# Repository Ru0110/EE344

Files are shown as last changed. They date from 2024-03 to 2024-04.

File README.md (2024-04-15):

# EE344
Auto-dialling Alarm System for Temperature and Humidity Monitoring

## File organization
The following folders will be present in the root directory of the project:
- `energy_meter`: Contains KiCad design files for the sensing unit PCB
- `Software`: Contains all firmware used in the project
    - `RP2040_code`: Source code for the firmware of the sensing unit written using the RP2040 C/C++ SDK. The code may be built using CMake or the uf2 file in the build subdirectory may be flashed directly to the RPi Pico W.
    - `arduino_code`: Source code for the sensing unit based on arduino. Based on code provided by Analog Devices for the EVAL-ACE9000 SHIELDZ board.
    - `central_code`: Source code for the central unit written in MicroPython
    - Other python files are for setting up a TCP client to test data logging
- `CAD`: Contains files for the enclosures of the sensing unit and central unit  
- `Test`: Contains test data from a long-term test using an Air Conditioner
- `central_unit`: Contains KiCad design files for a central unit with a SIM800L module. This is not used in the final prototype but may be useful for future iterations
- `Website`: Contains Code for a locally hosted website to view real-time data from the sensing units 
- Documentation file
- README file (this file)

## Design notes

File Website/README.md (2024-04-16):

## Project Overview

This project includes the following HTML and CSS files:

* `index.html`: The main HTML page for the project.
* `style.css`: Stylesheet for the HTML page.

## Deployment

The HTML page is deployed using GitHub Pages and is currently accessible at: https://shleshgholap.github.io/EDL-Project/

## Waveform Visualization

* The `Waveform.html` file displays plots of voltage values and their periodograms. Currently, this visualization relies on a local server.
* **Enhancement:** To make the waveform visualization publicly accessible, consider migrating the plot generation process to a cloud computing service. This would enable seamless integration of the plots into the `index.html` page. 

**Key Points**

* The core HTML and CSS components are ready for deployment.
* The waveform visualization component requires modification to work within a publicly accessible deployment setup.

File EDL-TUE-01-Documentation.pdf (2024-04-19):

Auto-dialing Alarm System for Power,

# Temperature, and Humidity Monitoring

## EE344: Electronic Design Lab Group TUE-01

## Abhiruchi Kotamkar (2100700043) Shiv Bharuka (210070079) Shlesh Gholap (210070080) Shobhit Maheshwari (210070081)

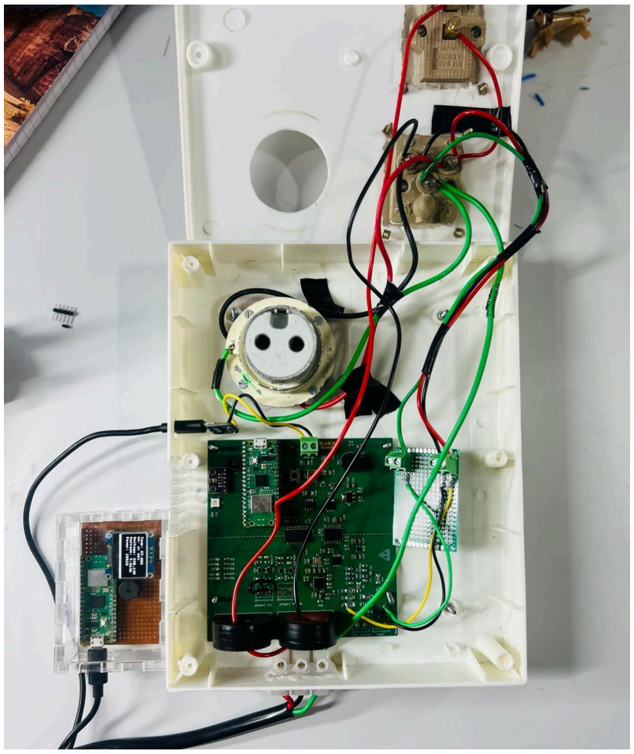
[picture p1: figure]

# Table of contents

Features and Overview | 3
File organization | 3
Hardware documentation | 4
Sensing unit | 4
Changes from the EVAL-ADE9000 SHIELDZ | 4
Isolation circuitry | 5
Voltage and current channel calculations | 5
Other peripherals | 5
Troubleshooting | 5
Central unit | 6
Modules | 6
Software documentation | 7
Sensing unit | 7
ADE9000 driver | 7
BME280 driver | 7
Wireless communication | 7
EEPROM in Flash | 7
Central unit | 7
OLED Display | 8
Buzzer | 8
MongoDB | 8
Website | 9
Push Notifications and Mailing | 9
Possible future work | 10
Additional references | 10

# Features and Overview

- Continuous health monitoring and alarm system for high-power appliances such as Air Conditioners, Humidity Regulators, Lab equipment, and all appliances up to 20kW.
- Machine health monitoring by analyzing harmonic distortions in voltage waveform
- Data such as power consumption, local temperature and humidity, and voltage waveform are uploaded to a remote database accessible from anywhere.
- Multi-unit integration over LAN in a setting such as a laboratory or factory with the help of a central unit that coordinates data logging.
- Alarm system with push notifications, email, and call-based alarms on user-defined thresholds for all monitored values provided by the central unit

# File organization

The following folders will be present in the root directory of the project:
- energy_meter: Contains KiCad design files for the sensing unit PCB
- Software: Contains all firmware used in the project
- RP2040_code: Source code for the firmware of the sensing unit written using the RP2040 C/C++ SDK. The code may be built using CMake or the uf2 file in the build subdirectory may be flashed directly to the RPi Pico W.
- arduino_code: Source code for the sensing unit based on arduino. Based on code provided by Analog Devices for the EVAL-ACE9000 SHIELDZ board.
- central_code: Source code for the central unit written in MicroPython
- Other python files are for setting up a TCP client to test data logging
- CAD: Contains files for the enclosures of the sensing unit and central unit
- Test: Contains test data from a long-term test using an Air Conditioner
- central_unit: Contains KiCad design files for a central unit with a SIM800L module. This is not used in the final prototype but may be useful for future iterations
- Website: Contains Code for a locally hosted website to view real-time data from the sensing units
- README file
- Documentation file (this file)

This documentation may be changed. Find the live version here: https://docs.google.com/document/d/e/2PACX-1vSk20U0GbC1EArys-i2jhloWY60GNWYztmFV4l-aTbJ1UrM4m5yABL2bQwfzQ4_mtzRKHXNJLR0H1ZW/pub (https://docs.google.com/document/d/e/2PACX-1vSk20U0GbC1EArys-i2jhloWY60GNWYztmFV4l-aTbJ1UrM4m5yABL2bQwfzQ4_mtzRKHXNJLR0H1ZW/pub)

# Hardware documentation

## Sensing unit

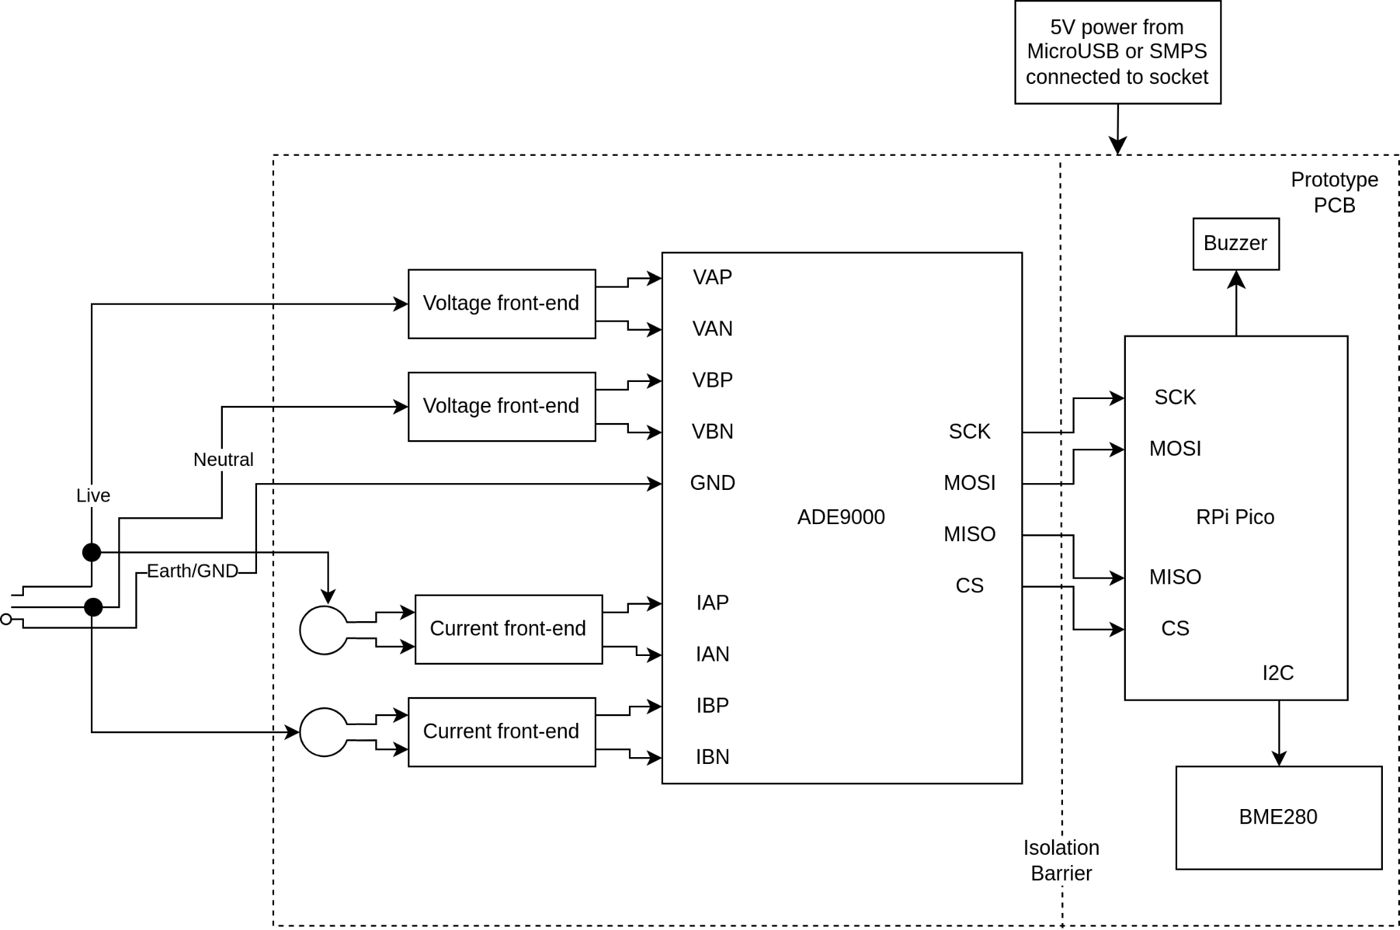
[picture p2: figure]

- Based on the ADE9000 Power Monitoring IC and the RPI Pico W Micro-controller
- Design is referenced from the design of the EVAL-ADE9000 SHIELDZ evaluation board with significant changes
- By default, the circuit will allow the ADE9000 to start in PowerMode 3 which
- allows SPI communication. Deep sleep can be toggled by the MCU

### Changes from the EVAL-ADE9000 SHIELDZ

- Only two current channels and two voltage channels (Live and Neutral) and a connector for the high powered side ground connection (Earth).
- We have added screw terminals to connect voltage sources. Along with the current transformer input, we have added screw terminals for current input as well
- The RaspberryPi Pico W is used instead of an Arduino Zero as both are 32 bit (ARM Cortex M0+) MCUs.
- We do not need the EEPROM as the flash memory of the RPi Pico is enough (2MB)
- The board requires 5V power. This can be drawn from a microUSB port or an SMPS or any equivalent 5V DC source. There are screw terminals and a microUSB connector for these connections

### Isolation circuitry

- The high-power circuit (ADE9000 and input channels) must be electrically isolated from the low-power logic circuitry. However, signals must be exchanged between them for the MCU to interpret data from the ADE9000
- An SPI isolator (ADuM4151) is used to transmit SPI signals (MOSI, MISO, SCLK,
- SS/CS)
- The ADE9000 does not receive power from the socket but instead from the power supply in the logic circuit. This power is fed using a power isolator (ADuM6404) at 5V. Some logic signals have to be level shifted to 5V and then back to 3.3V for transmission which is done by the SN74LV4T125PWR buffer.

### Voltage and current channel calculations

We are measuring power consumption of 1-Phase 3-Wire Residential sockets. According to the ADE9000 Technical Reference Manual, this requires two voltage channels and two current channels (one for the live wire and one for the neutral wire. The earth wire is used as ground for the high power circuit).

Burden resistors are used in current channels to prevent the inrush of current. A diode configuration similar to a bridge rectifier is used to allow for AC current. The voltage input is scaled down using a voltage divider circuit made of high-power resistors. Both the channels produce a differential input to the ADE9000

- Voltage divider:
- We have four 200kOhm resistors in series (instead of one resistor to manage heat dissipation) and a 1kOhm resistor across which the voltage is measured.
- This results in a gain of 1/(800+1) = 0.0012.
- A nominal voltage of 240 V rms is expected. The ADC will receive 0.299 V rms = 42.7% of full-scale reading.
- Current channel burden resistor:
- We are using a 1:2500 current transformer.
- The expected load for a three-star 2-ton AC is 7-8 A rms. The input to the ADE9000 must not exceed 0.707 V rms. Let us assume a typical sustained current of 10 A rms.
- Thus for the burden resistor we must have (10/2500)*2R < 0.707 or R < 88 ohm.
- We choose R = 20 for a nominal reading of 0.16 V rms = 25% of the full scale reading. The 24-bit ADC provides a good resolution (4.21e-8 V) for a small reading as well.

### Other peripherals

- BME280 sensor for temperature and humidity measurements
- RGB Led (WS2812B) for state indication
- Buzzer to act as a local alarm

### Troubleshooting

Recommended testing sequence is:
- Check voltage input at low power side: 5V

- Check voltage output of AMS1117: 3.3V
- Check voltage input to power isolator: 5V
- Check voltage output of power isolator: 5V
- Check voltage output of linear regulator at high-powered side: 3.3V
- Check reference voltages generated by ADE9000:
- AVDDOUT: 1.9V
- DVDDOUT: 1.7V
- REF: 1.25V
- Verify IRQ1 is low and IRQ0 is high through test pads
- Verify CS signal is high through test pad
- Verify SPI communication by polling the PART_ID register of the ADE9000

In the final prototype, we are using a zero-PCB with screw terminals and ferrite beads as input voltage channels due to a short circuit that happened during mains voltage testing which resulted in the voltage tracks getting damaged. This is not needed in any other sensing unit.

## Central unit

Implements the alarm system and acts as a bridge between multiple sensing units and the real-time interface for device health monitoring. Currently it is made by soldering modules on a perforated board or zero-PCB.

### Modules

- RPi Pico W
- 0.96 Inch OLED display
- Buzzer

# Software documentation

## Sensing unit

### ADE9000 driver

The driver is adapted from the Arduino code provided by Analog Devices (https://www.analog.com/en/resources/evaluation-hardware-and-software/evaluation-boards-kits/eval-ade9000-shield.html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) (https://www.analog.com/en/resources/evaluation-hardware-and-software/evaluation-boards-kits/eval-ade9000-shield.html) but optimized to work well with the C/C++ SDK of the RP2040. The register map is referenced from the datasheet. Wrapper functions for SPI communication are provided to make reading from registers in the ADE9000 easier. SPI burst read functions to read coherent sampled waveform data and decoherent sampled waveform data are also available. Function-wise documentation can be found in the code files.

### BME280 driver

The driver is built using the official C API for the BME280 provided by Bosch (https://github.com/boschsensortec/BME280_SensorAPI). I2C communication is used. All default settings are used as provided by Bosch.

### Wireless communication

The lwIP library creates a lightweight TCP server with one port (https://www.nongnu.org/lwip/2_1_x/group__tcp__raw.html). This continuously transmits data in the following form:
- Data from register polling such as Power, Temperature, and Humidity (60B)
- Waveform buffer1 (512B)
- Waveform buffer2 (512B)
The waveform buffers are to be concatenated to get ~4 cycles of voltage readings.
The server automatically restarts if the connection with a client is broken, which allows the central unit to poll multiple servers in quick succession. The sensing unit sends data on a specific IP address and Port which is required to be defined in the central unit.

### EEPROM in Flash

A customized linker script (memmap_custom.ld in Software/RP2040_code) is used to
reserve 16kB in the flash memory of the RPi Pico as non-volatile EEPROM used to store configuration data for the ADE9000. This eliminates the need for a separate EEPROM, which is used in the Analog Devices Shield

## Central unit

The complete implementation of the Central Unit is available in the repository at (Software/central_unit.py). The data received (60B + 512B + 512B) from the sensing unit via the TCP server gets unpacked and stored using the following decoding scheme:
- Time: Received as unsigned integer (first 4B)
- VArms, VBrms, IArms, IBrms: Voltage and current readings (Each 4B float)
- PowerA, PowerB: Power readings (Each 4B float)

- PfA, PfB: Power Factor reading (Each 4B float)
- freqA, freqB: Frequency readings (Each 4B float)
- Temperature, Pressure, Humidity: Environmental sensor readings received from BME280 (Each 4B float)
- emergency: Unsigned integer (4B) whose each bit represents a trigger in any of the defined parameters, providing 32 emergency interceptions.
- waveform_buffer: Stores the last 512 short integers (2B) representing waveform data.

### OLED Display

The temperature, relative humidity, voltage RMS, current RMS, and power readings are displayed on the 0.96-inch OLED display with a resolution of 128x64 pixels. Establishes communication with an SSD1306 OLED display over an I2C bus. The display used runs on the SSD1306 OLED driver. The MicroPython driver to display data on the display was taken from (https://github.com/stlehmann/micropython-ssd1306). Optionally displays a full-screen alert message, overriding the sensor data display in case any of the pre-defined thresholds are crossed.

### Buzzer

A buzzer is connected to a general-purpose input/output (GPIO) pin on the Raspberry Pi Pico. It specifically utilizes Pico's PWM (Pulse Width Modulation) hardware capabilities for volume control. The buzzer goes off if any of the pre-defined thresholds are crossed.
- Buzzer Pin: BUZZER_PIN (default: 15) specifies the GPIO pin connected to the buzzer.
- Sound Configuration: BUZZER_FREQUENCY (default: 500 Hz) sets the desired frequency of the buzzer sound. BUZZER_DURATION (default: 1 second) defines how long the buzzer will sound. BUZZER_DUTY_CYCLE (default: 100%) controls the buzzer's volume (when the signal is on within a cycle).
- Functions:
- play_buzzer(): Plays a buzzer sound with the configured parameters, using PWM for volume control.
- stop_buzzer(pin_num=15): Stops the buzzer sound, regardless of the play duration set in play_buzzer.

### MongoDB

The data(1084B) is received once every 10 seconds and is stored on an online database management service called MongoDB. MongoDB is a non-SQL-based service and mainly stored data as JSON files. MongoDB allows downloads of the data stored as CSV or JSON files. It also allows API calls to receive the data by running a simple Python script (Software/Mongodb_datascrap.py). Two databases were created on the MongoDB dashboard, one of which stores the waveform data and the other of which stores the rest of the sensor readings. Each data point received is sent to the respective databases using API calls before receiving the next data point.
The main reason for this slow sampling rate is that the uploads to the MongoDB database using API calls take a few seconds. This sampling rate can be improved using a more powerful microcontroller as a central unit or a self-hosted server(local or cloud-based). The API calls to MongoDB took less than a second when made from a Windows PC.

### Website

The data received on MongoDB is then used to create time-labeled interactive plots which are deployed on an HTML page (Website/index.html) that is hosted on GitHub pages. The plots are updated every minute, and the plots for the last 10 minutes are displayed, including temperature, relative humidity, voltage RMS, current RMS, and power readings. The website can also be accessed from phones and provides all the functionalities.
An additional aspect of the project was to analyze appliance health, which is done by looking at the voltage waveforms received at every data point. The data that was collected on the Waveform database of MongoDB is used to make voltage waveform plots along with a periodogram to identify the dominant voltage frequencies (Test/Waveform_plot.png). A bad appliance's health correlates with the frequency in the periodogram. Identifying frequencies other than 50 Hz in the periodogram hints at problems with the appliance’s health. A Python script (Software/waveform_plot.py) runs on a local server (can be scaled to an online host); it scraps the waveform data from the MongoDB database and stores the plots of waveform and periodogram assuming a sampling rate for voltage waveform as 8000, locally. The local server is then used to host the plot created on an HTML page (Website/waveform.html). Note that these plots can only update (with a refresh every 5 seconds) when a local server runs. An example of such a plot is shown on the website.

### Push Notifications and Mailing

One of the most important components of the project is alerting the user which is done by using a software called ntfy.sh, which is an HTTP-based Publisher-Subscriber notification service. Initially, users need to subscribe to a topic (we used EDLProjectTUE01) they want to receive the notifications. Users can connect to the topic from any device (phone, iPad, laptop) that supports ntfy.sh without the required to provide a phone number. If any thresholds get crossed, instantaneous and customized push notifications and emails are published on the topic and sent to the user’s email ID depending on the parameters that are not in the expected range. The central unit makes HTTP requests to connect to the service and send an alert message. The paid version of this service can even make calls that use a text-to-speech algorithm to convert the message into a robotic voice and make calls to specific users.

# Possible future work

- Improvement of waveform capture using decoherent sampling. Currently, coherent sampling is used with resampled data
- Providing power to the logic circuit through the mains itself (may use an SMPS)
- Multi-unit integration beyond three sensor units using a sensor mesh (may use Bluetooth instead of LAN). This would require operation without a central unit and uploading data directly to the cloud, making this a proper “IoT” device
- Analysis of long-term power consumption and waveform data to detect deterioration in device health
- Shrinking of form factor and re-design of outer case for ease of mounting

# Additional references

- Project github: https://github.com/Ru0110/EE344
- Project drive folder (contains BOM and other relevant files): https://drive.google.com/drive/folders/13c8EIVbcSlq_PN7hLz76V1K4JDQLavGz?usp=sharing (https://drive.google.com/drive/folders/13c8EIVbcSlq_PN7hLz76V1K4JDQLavGz?usp=sharing)
- The website that displays plots made: https://shleshgholap.github.io/EDL-Project/

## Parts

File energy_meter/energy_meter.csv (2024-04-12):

Qty | Reference(s) | Value
1 | BZ1 | Buzzer
8 | C1, C3, C4, C6, C7, C8, C9, C10 | 0.022u
2 | C2, C5 | 51p
2 | C11, C36 | 1u
2 | C12, C13 | 18p
19 | C14, C16, C18, C20, C22, C23, C24, C26, C28, C30, C31, C33, C35, C38, C39, C41, C44, C49, C51 | 0.1u
4 | C15, C17, C19, C37 | 4.7u
8 | C21, C25, C27, C29, C32, C34, C40, C42 | 10u
2 | C43, C50 | 22u
4 | CR1, CR2, CR3, CR4 | MMBD4148SE
5 | D1, D2, D3, D4, D5 | LED
3 | D6, D7, D8 | D_Schottky
1 | D9 | WS2812B
3 | FB1, FB2, FB3 | FerriteBead
4 | H1, H2, H3, H4 | MountingHole
1 | IC1 | ADUM4151BRIZ
1 | IC2 | ADUM6404ARIZ
1 | IC3 | ADP122AUJZ-3.3-R7
1 | IC4 | 24LC32A_SN
2 | J1, J2 | Screw_Terminal_01x02
1 | J3 | MicroUSB
1 | J8 | 5V_SMPS
1 | J9 | IA_in
1 | J10 | IB_in
1 | Q1 | Q_NMOS_SGD
8 | R1, R2, R3, R4, R9, R10, R12, R14 | 200k
9 | R5, R6, R11, R13, R15, R16, R19, R20, R35 | 1k
4 | R7, R8, R17, R18 | 20 ohm
1 | R21 | 10K
8 | R22, R23, R29, R30, R31, R32, R33, R34 | 10k
3 | R24, R25, R26 | 3K
2 | R27, R28 | 3k
2 | SW1, SW2 | SW_Push
1 | T1 | IA_in
1 | T2 | IB_in
1 | U1 | ADE9000ACPZ
2 | U2, U3 | SN74LV4T125PWR
1 | U4 | Pico_SMD_NODEBUG
1 | U5 | BME280
1 | U6 | AMS1117-3.3
1 | Y1 | Crystal_GND24

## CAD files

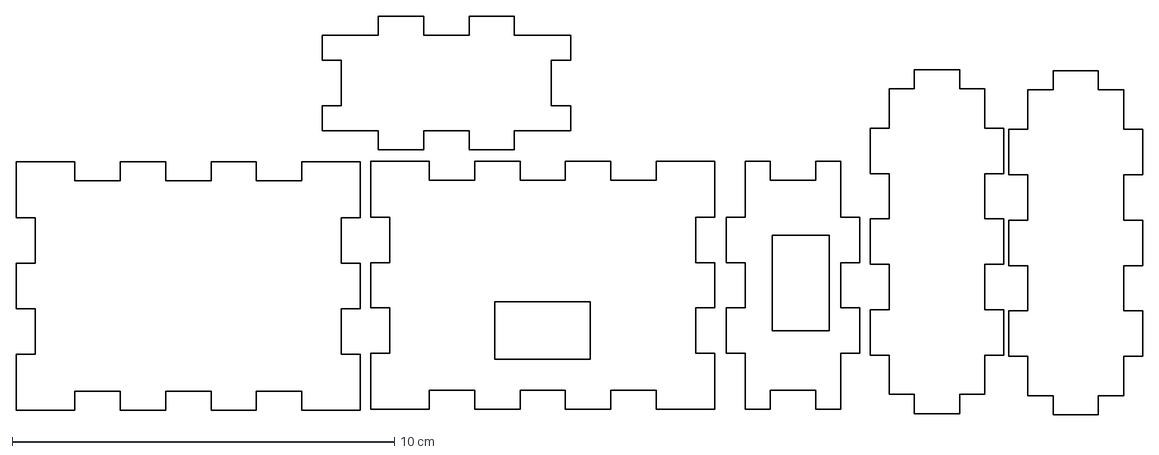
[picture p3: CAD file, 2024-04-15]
CAD/box final final.dxf
29.5 x 10.4 cm

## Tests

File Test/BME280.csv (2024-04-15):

Time | sum ( Humidity )
2024-04-05 16:29:33 | 32.21
2024-04-05 16:29:36 | 32.57
2024-04-05 16:29:38 | 32.44
2024-04-05 16:29:40 | 32.44
2024-04-05 16:29:44 | 32.43
2024-04-05 16:29:47 | 32.41
2024-04-05 16:29:50 | 32.45
2024-04-05 16:29:52 | 32.46
2024-04-05 16:29:54 | 32.44
2024-04-05 16:29:57 | 32.46
2024-04-05 16:29:59 | 32.47
2024-04-05 16:30:01 | 32.46
2024-04-05 16:30:04 | 32.45
2024-04-05 16:30:07 | 32.46
2024-04-05 16:30:10 | 32.46
2024-04-05 16:30:12 | 32.53
2024-04-05 16:30:14 | 32.53
2024-04-05 16:30:17 | 32.57
2024-04-05 16:30:19 | 32.59
2024-04-05 16:30:21 | 32.55
2024-04-05 16:30:23 | 32.57
2024-04-05 16:30:26 | 32.55
2024-04-05 16:30:28 | 32.55
2024-04-05 16:30:30 | 32.58
2024-04-05 16:30:32 | 32.64
2024-04-05 16:30:34 | 32.64
2024-04-05 16:30:37 | 32.66
2024-04-05 16:30:40 | 32.67
2024-04-05 16:30:42 | 32.67
2024-04-05 16:30:45 | 32.71
2024-04-05 16:30:48 | 32.73
2024-04-05 16:30:50 | 32.7
2024-04-05 16:30:53 | 32.7
2024-04-05 16:30:55 | 32.69
2024-04-05 16:30:58 | 32.7
2024-04-05 16:31:00 | 32.7
2024-04-05 16:31:03 | 32.7
2024-04-05 16:31:05 | 32.74
2024-04-05 16:31:07 | 32.82
2024-04-05 16:31:09 | 32.82
2024-04-05 16:31:11 | 32.82
2024-04-05 16:31:14 | 32.79
2024-04-05 16:31:17 | 32.77
2024-04-05 16:31:19 | 32.74
2024-04-05 16:31:21 | 37.44
2024-04-05 16:31:23 | 50.4
2024-04-05 16:31:25 | 39.95
2024-04-05 16:31:28 | 52.47
2024-04-05 16:31:30 | 41.21
2024-04-05 16:31:33 | 35.55
2024-04-05 16:31:35 | 34.21
2024-04-05 16:31:38 | 33.56
2024-04-05 16:31:40 | 33.1
2024-04-05 16:31:42 | 32.98
2024-04-05 16:31:45 | 32.81
2024-04-05 16:31:47 | 32.69
2024-04-05 16:31:50 | 32.66
2024-04-05 16:31:52 | 32.63
2024-04-05 16:31:54 | 32.61
2024-04-05 16:31:56 | 32.59
2024-04-05 16:31:59 | 32.58
2024-04-05 16:32:01 | 32.59
2024-04-05 16:32:04 | 32.57
2024-04-05 16:32:06 | 32.63
2024-04-05 16:32:08 | 46.15
2024-04-05 16:32:11 | 39.48
2024-04-05 16:32:14 | 35.22
2024-04-05 16:32:16 | 33.92
2024-04-05 16:32:18 | 33.46
2024-04-05 16:32:21 | 33.29
2024-04-05 16:32:24 | 33.04
2024-04-05 16:32:26 | 32.88
2024-04-05 16:32:28 | 32.85
2024-04-05 16:32:31 | 32.79
2024-04-05 16:32:34 | 32.77
2024-04-05 16:32:35 | 44
2024-04-05 16:32:38 | 36.67
2024-04-05 16:32:40 | 33.97
2024-04-05 16:32:43 | 33.35
2024-04-05 16:32:46 | 33.16
2024-04-05 16:32:48 | 32.95
2024-04-05 16:32:51 | 32.89
2024-04-05 16:32:53 | 32.77
2024-04-05 16:32:56 | 32.71
2024-04-05 16:32:58 | 32.7
2024-04-05 16:33:01 | 32.93
2024-04-05 16:33:03 | 32.83
2024-04-05 16:33:05 | 33
2024-04-05 16:33:09 | 33.08
2024-04-05 16:33:11 | 32.84
2024-04-05 16:33:14 | 32.78
2024-04-05 16:33:16 | 32.74
2024-04-05 16:33:18 | 32.83
2024-04-05 16:33:21 | 32.85
2024-04-05 16:33:25 | 32.83
2024-04-05 16:33:28 | 32.81
2024-04-05 16:33:29 | 32.81
2024-04-05 16:33:32 | 32.78
2024-04-05 16:33:34 | 32.94
2024-04-05 16:33:37 | 32.86
2024-04-05 16:33:39 | 32.85
2024-04-05 16:33:42 | 32.85
2024-04-05 16:33:44 | 32.91
2024-04-05 16:33:47 | 32.78
2024-04-05 16:33:49 | 32.69
2024-04-05 16:33:51 | 32.64
2024-04-05 16:33:55 | 32.6
2024-04-05 16:33:57 | 32.53
2024-04-05 16:33:59 | 32.62
2024-04-05 16:34:01 | 32.5
2024-04-05 16:34:03 | 32.63
2024-04-05 16:34:05 | 32.62
2024-04-05 16:34:08 | 32.6
2024-04-05 16:34:10 | 32.61
2024-04-05 16:34:12 | 32.6
2024-04-05 16:34:15 | 32.56
2024-04-05 16:34:17 | 32.5
2024-04-05 16:34:20 | 32.46
2024-04-05 16:34:22 | 32.43
2024-04-05 16:34:25 | 32.46
2024-04-05 16:34:32 | 32.46
2024-04-05 16:34:34 | 32.43
2024-04-05 16:34:37 | 32.46
2024-04-05 16:34:39 | 32.47
2024-04-05 16:34:42 | 32.48
2024-04-05 16:34:44 | 32.35
2024-04-05 16:34:47 | 32.34
2024-04-05 16:34:50 | 32.34
2024-04-05 16:34:51 | 32.34
2024-04-05 16:34:54 | 32.33
2024-04-05 16:34:56 | 32.32
2024-04-05 16:34:59 | 32.32
2024-04-05 16:35:01 | 32.29
2024-04-05 16:35:04 | 32.33
2024-04-05 16:35:06 | 32.43
2024-04-05 16:35:09 | 32.38
2024-04-05 16:35:12 | 32.4
2024-04-05 16:35:14 | 32.39
2024-04-05 16:35:17 | 32.42
2024-04-05 16:35:20 | 32.61
2024-04-05 16:35:22 | 32.48
2024-04-05 16:35:24 | 32.55
2024-04-05 16:35:26 | 32.36
2024-04-05 16:35:28 | 32.35
2024-04-05 16:35:31 | 32.32
2024-04-05 16:35:34 | 32.27
2024-04-05 16:35:36 | 32.22
2024-04-05 16:35:39 | 32.21
2024-04-05 16:35:42 | 32.27
2024-04-05 16:35:43 | 32.25
2024-04-05 16:35:46 | 32.31
2024-04-05 16:35:48 | 32.31
2024-04-05 16:35:51 | 32.28
2024-04-05 16:35:53 | 32.32
2024-04-05 16:35:56 | 32.36
2024-04-05 16:35:59 | 32.28
2024-04-05 16:36:02 | 32.25
2024-04-05 16:36:04 | 32.2
2024-04-05 16:36:06 | 32.17
2024-04-05 16:36:09 | 32.19
2024-04-05 16:36:11 | 32.27
2024-04-05 16:36:13 | 32.23
2024-04-05 16:36:16 | 32.5
2024-04-05 16:36:18 | 32.24
2024-04-05 16:36:20 | 32.33
2024-04-05 16:36:22 | 32.28
2024-04-05 16:36:25 | 32.26
2024-04-05 16:36:27 | 32.18
2024-04-05 16:36:29 | 32.25
2024-04-05 16:36:32 | 32.22
2024-04-05 16:36:34 | 32.23
2024-04-05 16:36:37 | 32.27
2024-04-05 16:36:39 | 32.33
2024-04-05 16:36:42 | 32.35
2024-04-05 16:36:45 | 32.32
2024-04-05 16:36:47 | 32.24
2024-04-05 16:36:49 | 32.23
2024-04-05 16:36:52 | 32.16
2024-04-05 16:36:57 | 32.23
2024-04-05 16:36:58 | 32.14
2024-04-05 16:37:01 | 32.17
2024-04-05 16:37:03 | 32.26
2024-04-05 16:37:05 | 32.23
2024-04-05 16:37:06 | 32.26
2024-04-05 16:37:09 | 32.28
2024-04-05 16:37:12 | 32.33
2024-04-05 16:37:14 | 32.31
2024-04-05 16:37:16 | 32.38
2024-04-05 16:37:18 | 32.4
2024-04-05 16:37:20 | 32.41
2024-04-05 16:37:22 | 32.41
2024-04-05 16:37:23 | 32.37
2024-04-05 16:37:26 | 32.38
2024-04-05 16:37:29 | 32.43
2024-04-05 16:37:31 | 32.37
2024-04-05 16:37:33 | 32.34
2024-04-05 16:37:36 | 32.31
2024-04-05 16:37:38 | 32.42
2024-04-05 16:37:40 | 32.39
2024-04-05 16:37:42 | 32.32
2024-04-05 16:37:43 | 32.32
2024-04-05 16:37:45 | 32.37
2024-04-05 16:37:47 | 32.39
2024-04-05 16:37:49 | 32.3
2024-04-05 16:37:52 | 32.48
2024-04-05 16:37:54 | 32.38
2024-04-05 16:37:56 | 32.35
2024-04-05 16:37:58 | 32.35
2024-04-05 16:38:01 | 32.33
2024-04-05 16:38:03 | 32.31
2024-04-05 16:38:05 | 32.36
2024-04-05 16:38:08 | 32.36
2024-04-05 16:38:10 | 32.4
2024-04-05 16:38:12 | 32.47
2024-04-05 16:38:14 | 32.61
2024-04-05 16:38:16 | 32.66
2024-04-05 16:38:18 | 32.55
2024-04-05 16:38:21 | 32.56
2024-04-05 16:38:23 | 32.58
2024-04-05 16:38:25 | 32.51
2024-04-05 16:38:28 | 32.61
2024-04-05 16:38:31 | 32.55
2024-04-05 16:38:33 | 32.57
2024-04-05 16:38:35 | 32.56
2024-04-05 16:38:37 | 32.6
2024-04-05 16:38:39 | 32.6
2024-04-05 16:38:42 | 32.67
2024-04-05 16:38:44 | 32.7
2024-04-05 16:38:46 | 32.73
2024-04-05 16:38:49 | 32.74
2024-04-05 16:38:51 | 32.81
2024-04-05 16:38:53 | 32.83
2024-04-05 16:38:56 | 32.83
2024-04-05 16:38:58 | 32.82
2024-04-05 16:39:00 | 32.81
2024-04-05 16:39:02 | 32.84
2024-04-05 16:39:04 | 32.85
2024-04-05 16:39:07 | 32.89
2024-04-05 16:39:09 | 32.93
2024-04-05 16:39:12 | 32.95
2024-04-05 16:39:14 | 32.93
2024-04-05 16:39:16 | 32.95
2024-04-05 16:39:18 | 33
2024-04-05 16:39:20 | 33.02
2024-04-05 16:39:22 | 33.05
2024-04-05 16:39:24 | 33.02
2024-04-05 16:39:25 | 32.98
2024-04-05 16:39:28 | 32.96
2024-04-05 16:39:30 | 32.92
2024-04-05 16:39:32 | 32.91
2024-04-05 16:39:35 | 32.87
2024-04-05 16:39:37 | 32.91
2024-04-05 16:39:39 | 32.93
2024-04-05 16:39:41 | 32.95
2024-04-05 16:39:44 | 32.95
2024-04-05 16:39:46 | 32.99
2024-04-05 16:39:49 | 32.98
2024-04-05 16:39:51 | 32.99
2024-04-05 16:39:53 | 32.99
2024-04-05 16:39:55 | 33
2024-04-05 16:39:58 | 32.99
2024-04-05 16:40:04 | 33.03
2024-04-05 16:40:07 | 33.06
2024-04-05 16:40:10 | 33.06
2024-04-05 16:40:13 | 33.09
2024-04-05 16:40:16 | 33.12
2024-04-05 16:40:18 | 33.06
2024-04-05 16:40:21 | 33.05
2024-04-05 16:40:23 | 33.1
2024-04-05 16:40:28 | 33.05
2024-04-05 16:40:31 | 32.94
2024-04-05 16:40:35 | 32.93
2024-04-05 16:40:38 | 33
2024-04-05 16:40:41 | 32.97
2024-04-05 16:40:44 | 32.98
2024-04-05 16:40:45 | 32.93
2024-04-05 16:40:50 | 32.97
2024-04-05 16:40:54 | 33
2024-04-05 16:40:56 | 32.97
2024-04-05 16:40:58 | 32.97
2024-04-05 16:41:02 | 32.99
2024-04-05 16:41:05 | 32.89
2024-04-05 16:41:08 | 32.92
2024-04-05 16:41:10 | 32.9
2024-04-05 16:41:13 | 32.95
2024-04-05 16:41:16 | 32.91
2024-04-05 16:41:18 | 32.82
2024-04-05 16:41:21 | 32.91
2024-04-05 16:41:24 | 32.89
2024-04-05 16:41:27 | 32.91
2024-04-05 16:41:29 | 32.92
2024-04-05 16:41:32 | 32.91
2024-04-05 16:41:38 | 32.93
2024-04-05 16:41:40 | 32.93
2024-04-05 16:41:42 | 32.89
2024-04-05 16:41:45 | 32.92
2024-04-05 16:41:48 | 32.96
2024-04-05 16:41:52 | 32.98
2024-04-05 16:41:53 | 32.91
2024-04-05 16:41:57 | 32.9
2024-04-05 16:42:02 | 32.87
2024-04-05 16:42:05 | 32.92
2024-04-05 16:42:09 | 32.91
2024-04-05 16:42:12 | 32.81
2024-04-05 16:42:15 | 32.85
2024-04-05 16:42:17 | 32.88
2024-04-05 16:42:21 | 32.9
2024-04-05 16:42:23 | 32.84
2024-04-05 16:42:26 | 32.86
2024-04-05 16:42:30 | 32.87
2024-04-05 16:42:32 | 32.91
2024-04-05 16:42:34 | 32.91
2024-04-05 16:42:37 | 32.88
2024-04-05 16:42:40 | 32.85
2024-04-05 16:42:43 | 32.92
2024-04-05 16:42:44 | 32.94
2024-04-05 16:42:48 | 32.99
2024-04-05 16:42:51 | 33.63
2024-04-05 16:42:53 | 42.38
2024-04-05 16:42:55 | 40.14
2024-04-05 16:42:58 | 35.71
2024-04-05 16:43:01 | 34.2
2024-04-05 16:43:03 | 33.53
2024-04-05 16:43:05 | 33.39
2024-04-05 16:43:08 | 33.19
2024-04-05 16:43:11 | 33.13
2024-04-05 16:43:15 | 33.02
2024-04-05 16:43:17 | 39.2
2024-04-05 16:43:20 | 35.02
2024-04-05 16:43:23 | 33.99
2024-04-05 16:43:25 | 33.53
2024-04-05 16:43:28 | 34.17
2024-04-05 16:43:31 | 34.91
2024-04-05 16:43:35 | 33.76
2024-04-05 16:43:38 | 33.33
2024-04-05 16:43:41 | 33.14
2024-04-05 16:43:43 | 33.22
2024-04-05 16:43:46 | 33.04
2024-04-05 16:43:49 | 32.99
2024-04-05 16:43:52 | 32.98
2024-04-05 16:43:54 | 32.78
2024-04-05 16:43:57 | 32.63
2024-04-05 16:43:59 | 32.5
2024-04-05 16:44:02 | 32.46
2024-04-05 16:44:05 | 32.45
2024-04-05 16:44:12 | 32.47
2024-04-05 16:44:14 | 32.36
2024-04-05 16:44:17 | 32.36
2024-04-05 16:44:20 | 32.37
2024-04-05 16:44:22 | 32.29
2024-04-05 16:44:25 | 32.21
2024-04-05 16:44:28 | 32.18
2024-04-05 16:44:31 | 32.22
2024-04-05 16:44:34 | 32.19
2024-04-05 16:44:36 | 32.23
2024-04-05 16:44:38 | 32.23
2024-04-05 16:44:41 | 32.21
2024-04-05 16:44:43 | 32.16
2024-04-05 16:44:45 | 32.15
2024-04-05 16:44:48 | 32.14
2024-04-05 16:44:51 | 32.06
2024-04-05 16:44:52 | 32.08
2024-04-05 16:44:56 | 32.08
2024-04-05 16:44:58 | 32.04
2024-04-05 16:45:00 | 31.98
2024-04-05 16:45:03 | 31.99
2024-04-05 16:45:05 | 31.88
2024-04-05 16:45:08 | 31.82
2024-04-05 16:45:12 | 31.84
2024-04-05 16:45:14 | 31.84
2024-04-05 16:45:17 | 31.81
2024-04-05 16:45:20 | 31.83
2024-04-05 16:45:22 | 31.62
2024-04-05 16:45:24 | 31.56
2024-04-05 16:45:27 | 31.6
2024-04-05 16:45:30 | 31.61
2024-04-05 16:45:33 | 31.43
2024-04-05 16:45:36 | 31.52
2024-04-05 16:45:39 | 31.53
2024-04-05 16:45:41 | 31.52
2024-04-05 16:45:44 | 31.52
2024-04-05 16:45:47 | 31.49
2024-04-05 16:45:49 | 31.52
2024-04-05 16:45:53 | 31.49
2024-04-05 16:45:55 | 31.41
2024-04-05 16:45:57 | 31.33
2024-04-05 16:46:00 | 31.33
2024-04-05 16:46:05 | 31.3
2024-04-05 16:46:07 | 31.4
2024-04-05 16:46:09 | 31.47
2024-04-05 16:46:12 | 31.41
2024-04-05 16:46:16 | 31.37
2024-04-05 16:46:18 | 31.41
2024-04-05 16:46:20 | 31.47
2024-04-05 16:46:23 | 31.39
2024-04-05 16:46:25 | 31.36
2024-04-05 16:46:28 | 31.41
2024-04-05 16:46:32 | 31.42
2024-04-05 16:46:35 | 31.33
2024-04-05 16:46:38 | 31.31
2024-04-05 16:46:42 | 31.35
2024-04-05 16:46:44 | 31.34
2024-04-05 16:46:47 | 31.43
2024-04-05 16:46:49 | 31.4
2024-04-05 16:46:52 | 31.37
2024-04-05 16:46:58 | 31.33
2024-04-05 16:47:03 | 31.35
2024-04-05 16:47:05 | 31.33
2024-04-05 16:47:08 | 31.3
2024-04-05 16:47:10 | 47.52
2024-04-05 16:47:15 | 46.65
2024-04-05 16:47:17 | 37.03
2024-04-05 16:47:19 | 34.04
2024-04-05 16:47:22 | 33.18
2024-04-05 16:47:24 | 32.78
2024-04-05 16:47:31 | 32.43
2024-04-05 16:47:33 | 32.23
2024-04-05 16:47:37 | 32.1
2024-04-05 16:47:39 | 32.26
2024-04-05 16:47:43 | 32.12
2024-04-05 16:47:46 | 32.32
2024-04-05 16:47:48 | 32.03
2024-04-05 16:47:50 | 31.96
2024-04-05 16:47:53 | 31.92
2024-04-05 16:47:56 | 32
2024-04-05 16:48:00 | 32.05
2024-04-05 16:48:02 | 32.04
2024-04-05 16:48:04 | 31.97
2024-04-05 16:48:07 | 31.89
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

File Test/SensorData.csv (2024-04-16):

_id | freqA | VBrms | IBrms | PfB | VArms | PfA | freqB | Pressure | PowerB | IArms | Humidity | PowerA | Time | Temperature (C)
661a980c9bb71ef6fa2057c2 | 49.95768 | 1.016217 | 0.0 | 1.0 | 238.2267 | 1.0 | 50.0252 | 100359.8 | 0.0 | 0.000303515 | 46.6241 | 0.05804258 | 2024-04-13 20:04:50 | 28.25796
661a98159022aa2f4055c068 | 49.94805 | 0.9961557 | 0.0 | 1.0 | 237.7338 | 1.0 | 50.15064 | 100362.2 | 0.0 | 0.000303515 | 46.09187 | 0.05997734 | 2024-04-13 20:04:59 | 28.14105
661a98206dab85cab1c08d47 | 49.94564 | 1.022203 | 0.0 | 1.0 | 237.7935 | 1.0 | 49.85245 | 100365.2 | 0.0 | 0.000303515 | 46.49449 | 0.06191208 | 2024-04-13 20:05:11 | 28.04447
661a982d74aefea7fd09f919 | 49.95216 | 0.9685292 | 0.0 | 1.0 | 238.0849 | 1.0 | 49.99974 | 100367.0 | 0.0 | 0.000303515 | 46.49443 | 0.06191208 | 2024-04-13 20:05:23 | 28.03939
661a98380bd02188081709be | 49.94696 | 1.005741 | 0.0 | 1.0 | 238.0597 | 1.0 | 49.89901 | 100370.6 | 0.0 | 0.000303515 | 46.64256 | 0.05804258 | 2024-04-13 20:05:34 | 27.89706
661a98439bb71ef6fa208404 | 49.94794 | 1.109853 | 0.0 | 1.0 | 237.9712 | 0.9836066 | 50.03697 | 100362.3 | 0.0 | 0.000303515 | 47.10189 | 0.05900996 | 2024-04-13 20:05:46 | 27.7649
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

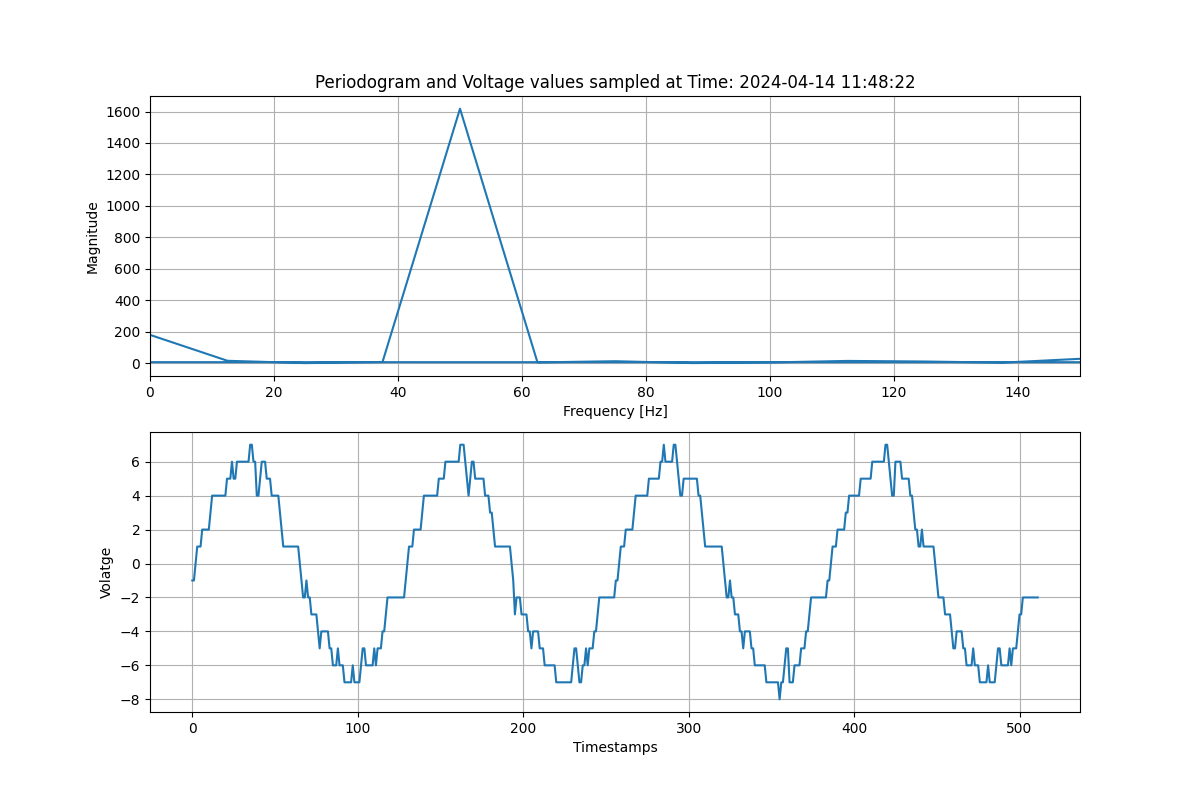
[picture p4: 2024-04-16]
Test/Waveform_plot2.png

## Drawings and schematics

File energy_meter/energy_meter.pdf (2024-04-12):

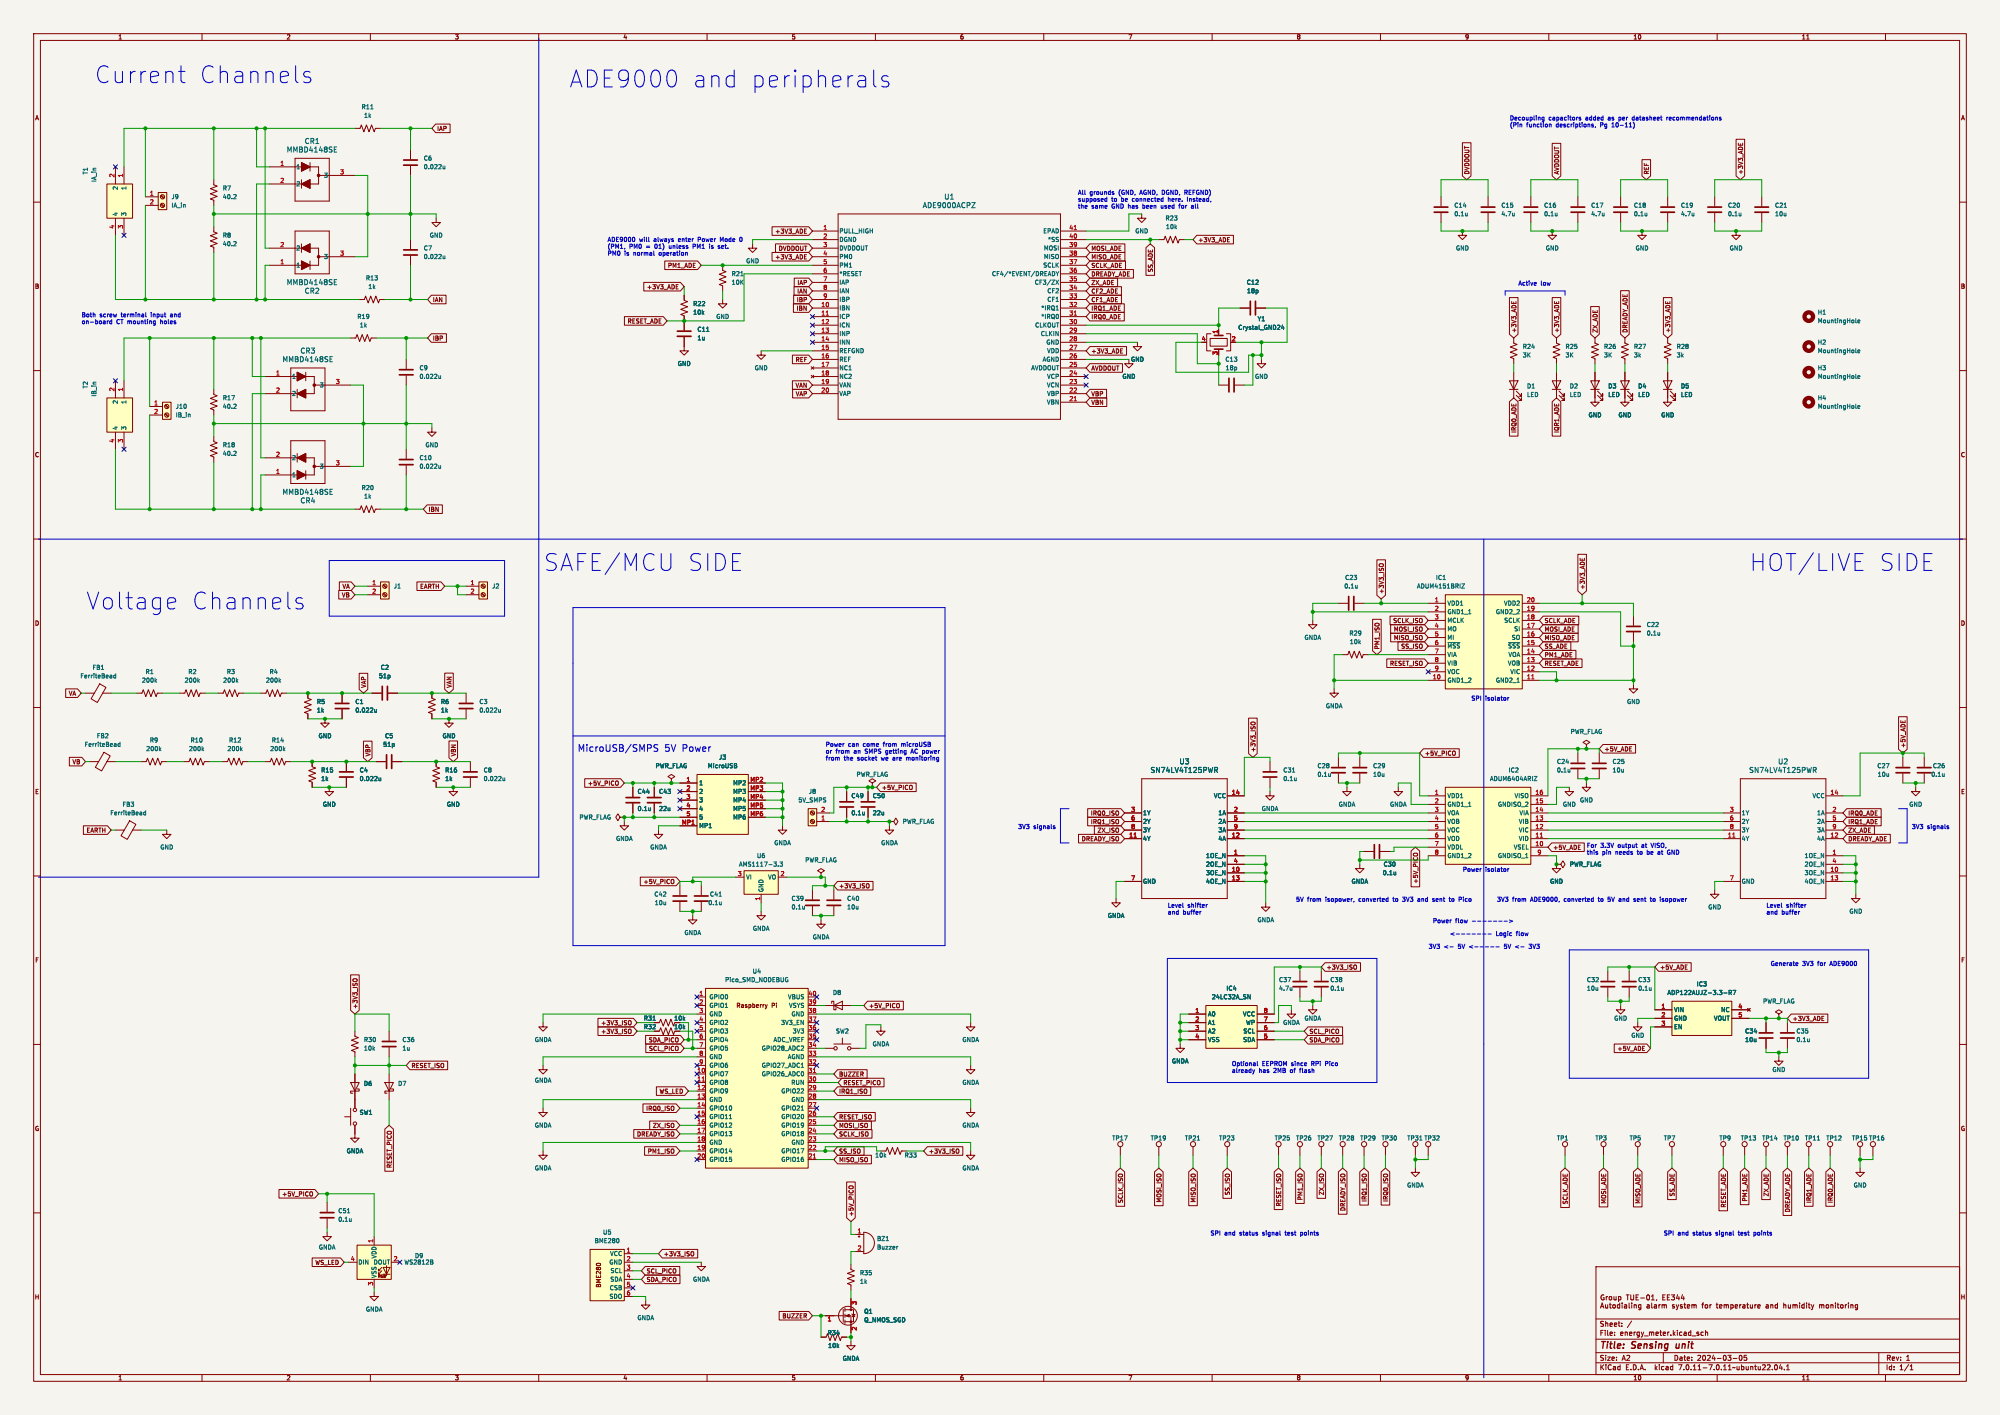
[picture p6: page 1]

All grounds (GND, AGND, DGND, REFGND)
the same GND has been used for all
10k GNDGND

ADE9000 will always enter Power Mode 0
(PM1, PM0 = 01) unless PM1 is set. PM0 is normal operation

LED
Level shifter and buffer HOT/LIVE SIDE

Power can come from microUSB
or from an SMPS getting AC power
from the socket we are monitoring

For 3.3V output at VISO,
this pin needs to be at GND
PWR_FLAG

Level shifter and buffer

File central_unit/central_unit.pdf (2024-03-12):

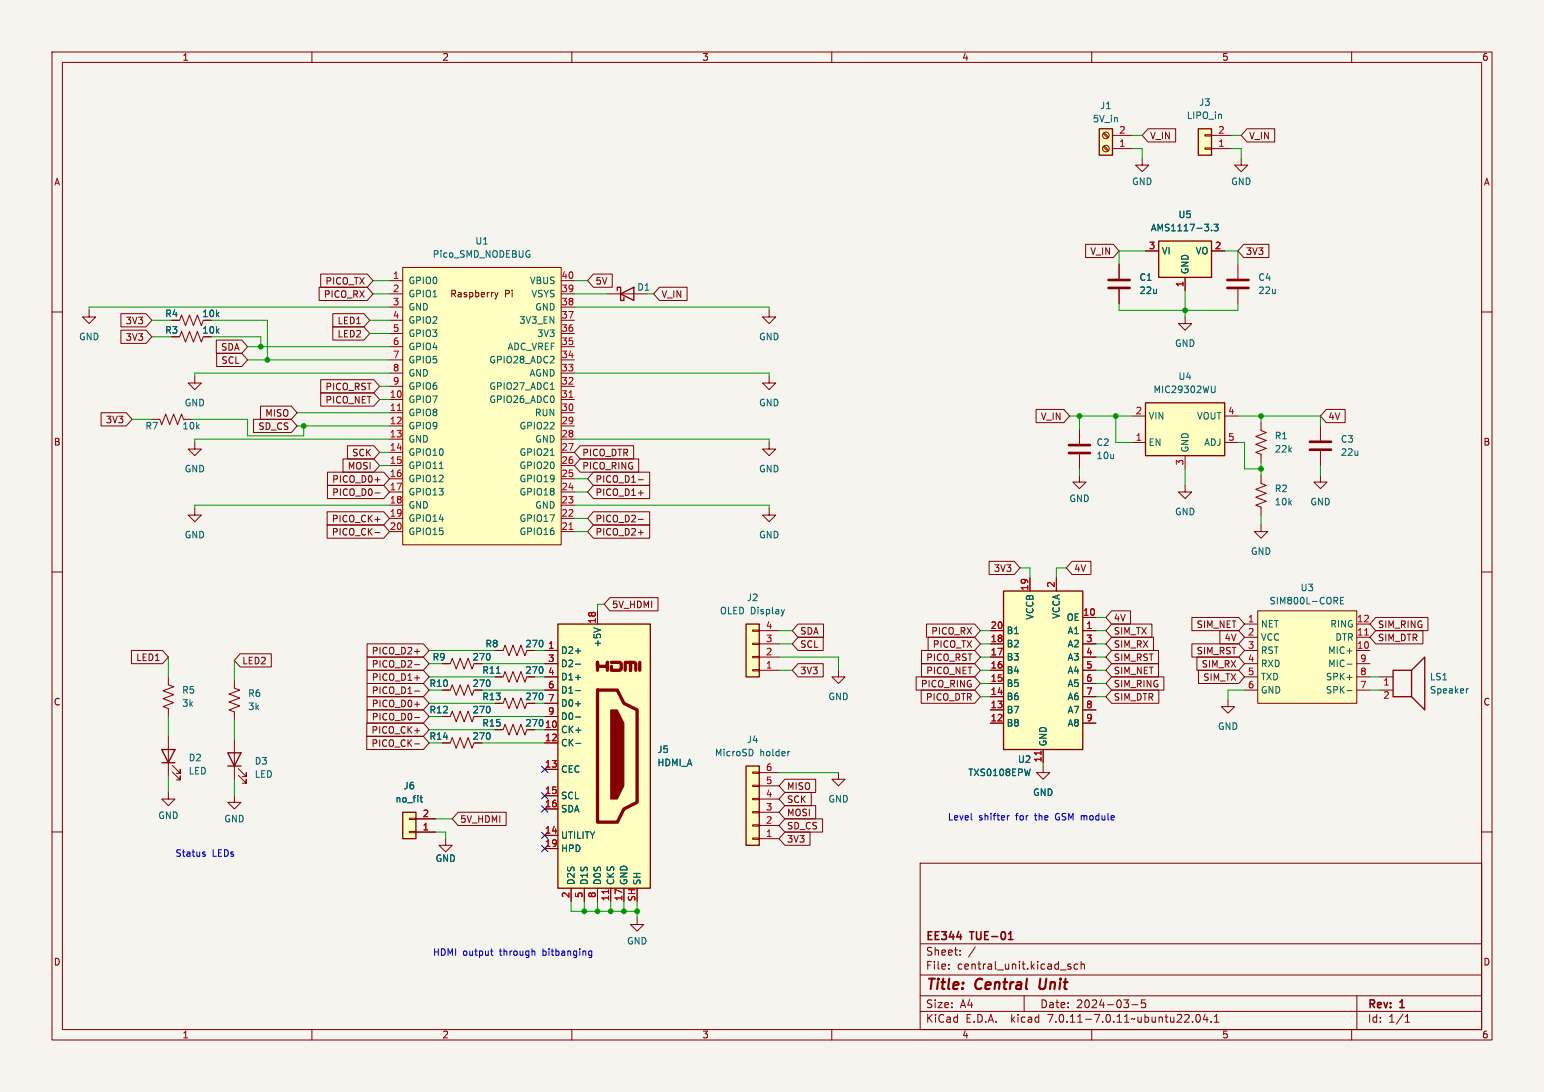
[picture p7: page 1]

J4 MicroSD holder GND GND

Level shifter for the GSM module Status LEDs

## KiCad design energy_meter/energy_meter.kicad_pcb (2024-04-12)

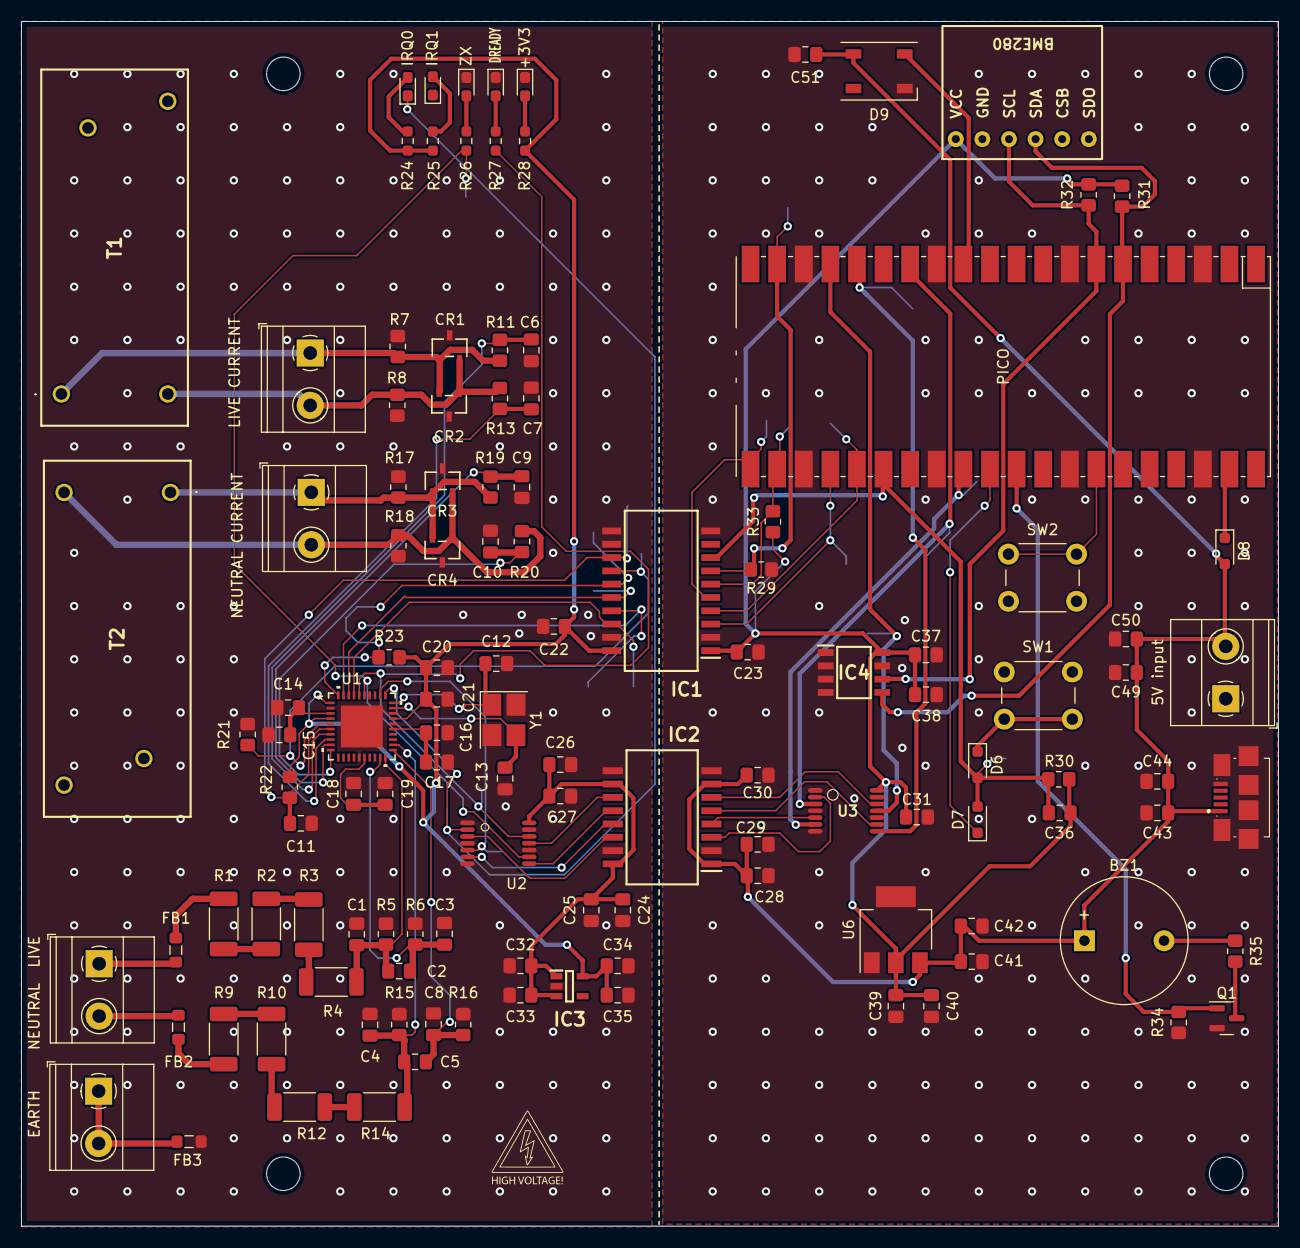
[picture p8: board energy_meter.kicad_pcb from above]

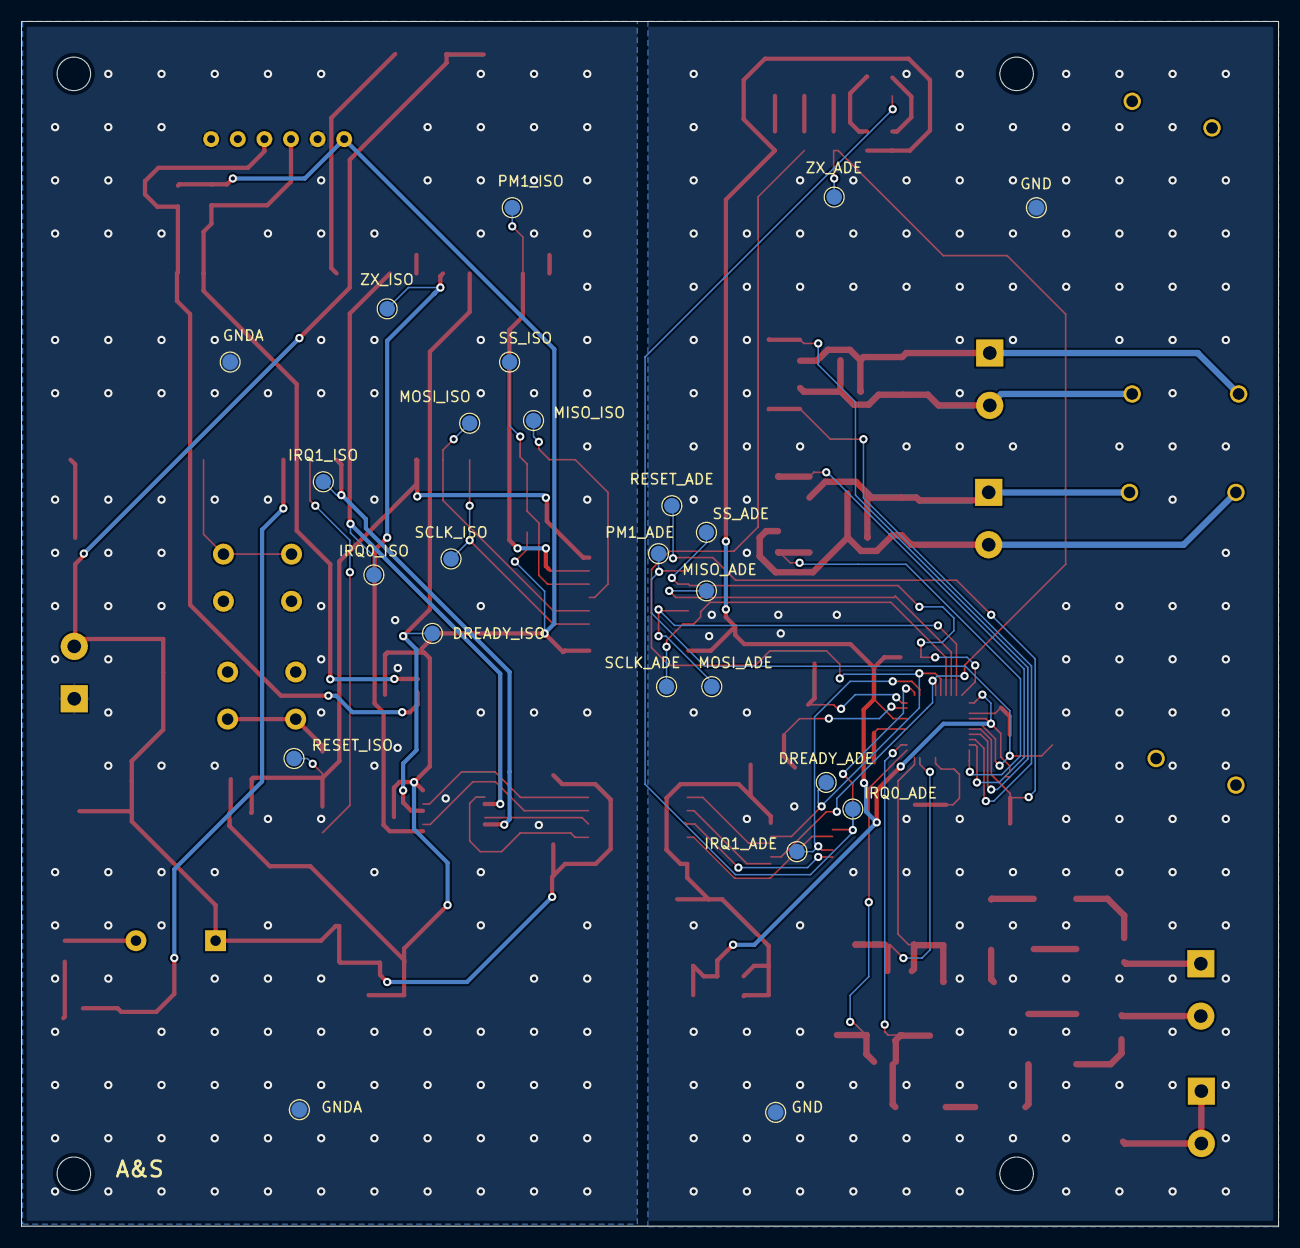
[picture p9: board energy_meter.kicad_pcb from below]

Board: 2 copper layers, 120.0 x 115.0 mm, 149 parts (24 on the bottom side), 77 nets.

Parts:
5V input: 5V_SMPS; TerminalBlock_Phoenix_MKDS-1,5-2_1x02_P5.00mm_Horizontal
+3V3: LED; LED_0603_1608Metric_Pad1.05x0.95mm_HandSolder
BZ1: Buzzer; Buzzer_12x9.5RM7.6
C1, C3, C4, C6, C7, C8, C9, C10: 0.022u; C_0805_2012Metric_Pad1.18x1.45mm_HandSolder
C2, C5: 51p; C_0805_2012Metric_Pad1.18x1.45mm_HandSolder
C11, C36: 1u; C_0805_2012Metric_Pad1.18x1.45mm_HandSolder
C12, C13: 18p; C_0805_2012Metric_Pad1.18x1.45mm_HandSolder
C14, C16, C18, C20, C22, C23, C24, C26, C28, C30, C31, C33, C35, C38, C39, C41, C44, C49, C51: 0.1u; C_0805_2012Metric_Pad1.18x1.45mm_HandSolder
C15, C17, C19, C37: 4.7u; C_0805_2012Metric_Pad1.18x1.45mm_HandSolder
C21, C25, C27, C29, C32, C34, C40, C42: 10u; C_0805_2012Metric_Pad1.18x1.45mm_HandSolder
C43, C50: 22u; C_0805_2012Metric_Pad1.18x1.45mm_HandSolder
CR1, CR2, CR3, CR4: MMBD4148SE; SOT-23TO-236_318-AT_OSI
D6, D7, D8: D_Schottky; D_SOD-323_HandSoldering
D9: WS2812B; LED_WS2812B_PLCC4_5.0x5.0mm_P3.2mm
DREADY: LED; LED_0603_1608Metric_Pad1.05x0.95mm_HandSolder
DREADY_ADE: TestPoint; TestPoint_Pad_D1.5mm
DREADY_ISO: TestPoint; TestPoint_Pad_D1.5mm
FB1, FB2, FB3: FerriteBead; L_0805_2012Metric_Pad1.05x1.20mm_HandSolder
GND: TestPoint; TestPoint_Pad_D1.5mm
GND#2: TestPoint; TestPoint_Pad_D1.5mm
GNDA: TestPoint; TestPoint_Pad_D1.5mm
GNDA#2: TestPoint; TestPoint_Pad_D1.5mm
H1, H2, H3, H4: MountingHole; MountingHole_3.2mm_M3
IC1: ADUM4151BRIZ; SOIC127P1031X264-20N
IC2: ADUM6404ARIZ; SOIC127P1032X265-16N
IC3: ADP122AUJZ-3.3-R7; SOT95P280X100-5N
IC4: 24LC32A_SN; SOIC127P600X175-8N
IRQ0, IRQ1: LED; LED_0603_1608Metric_Pad1.05x0.95mm_HandSolder
IRQ0_ADE, IRQ0_ISO, IRQ1_ADE, IRQ1_ISO: TestPoint; TestPoint_Pad_D1.5mm
J1, J2: Screw_Terminal_01x02; TerminalBlock_Phoenix_MKDS-1,5-2_1x02_P5.00mm_Horizontal
J3: MicroUSB; ZX62AB5PA31
LIVE CURRENT: IA_in; TerminalBlock_Phoenix_MKDS-1,5-2_1x02_P5.00mm_Horizontal
MISO_ADE: TestPoint; TestPoint_Pad_D1.5mm
MISO_ISO: TestPoint; TestPoint_Pad_D1.5mm
MOSI_ADE: TestPoint; TestPoint_Pad_D1.5mm
MOSI_ISO: TestPoint; TestPoint_Pad_D1.5mm
NEUTRAL CURRENT: IB_in; TerminalBlock_Phoenix_MKDS-1,5-2_1x02_P5.00mm_Horizontal
PICO: Pico_SMD_NODEBUG; RPi_PicoW_SMD
PM1_ADE, PM1_ISO: TestPoint; TestPoint_Pad_D1.5mm
Q1: Q_NMOS_SGD; SOT-23
R1, R2, R3, R4, R9, R10, R12, R14: 200k; R_2010_5025Metric_Pad1.40x2.65mm_HandSolder
R5, R6, R11, R13, R15, R16, R19, R20, R35: 1k; R_0805_2012Metric_Pad1.20x1.40mm_HandSolder
R7, R8, R17, R18: 40.2; R_0805_2012Metric_Pad1.20x1.40mm_HandSolder
R21: 10K; R_0805_2012Metric_Pad1.20x1.40mm_HandSolder
R22, R23, R29, R30, R31, R32, R33, R34: 10k; R_0805_2012Metric_Pad1.20x1.40mm_HandSolder
R24, R25, R26: 3K; R_0603_1608Metric_Pad0.98x0.95mm_HandSolder
R27, R28: 3k; R_0603_1608Metric_Pad0.98x0.95mm_HandSolder
RESET_ADE: TestPoint; TestPoint_Pad_D1.5mm
RESET_ISO: TestPoint; TestPoint_Pad_D1.5mm
SCLK_ADE: TestPoint; TestPoint_Pad_D1.5mm
SCLK_ISO: TestPoint; TestPoint_Pad_D1.5mm
SS_ADE: TestPoint; TestPoint_Pad_D1.5mm
SS_ISO: TestPoint; TestPoint_Pad_D1.5mm
SW1, SW2: SW_Push; SW_PUSH_6mm
T1: IA_in; T60404E4626X502
T2: IB_in; T60404E4626X502
U1: ADE9000ACPZ; ADE9000ACPZ_ADI
U2, U3: SN74LV4T125PWR; PW0014A_N
U5: BME280; BME_breakout
U6: AMS1117-3.3; SOT-223-3_TabPin2
Y1: Crystal_GND24; Crystal_SMD_3225-4Pin_3.2x2.5mm_HandSoldering
ZX: LED; LED_0603_1608Metric_Pad1.05x0.95mm_HandSolder
ZX_ADE: TestPoint; TestPoint_Pad_D1.5mm
ZX_ISO: TestPoint; TestPoint_Pad_D1.5mm

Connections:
+3V3_ADE: C20.1, C21.1, C22.1, C34.1, C35.1, IC1.20 (VDD2), IC3.5 (VOUT), R22.1, R23.2, R24.1, R25.1, R28.1, U1.1 (PULL_HIGH), U1.4 (PM0), U1.27 (VDD)
+3V3_ISO: C23.2, C31.1, C36.1, C37.1, C38.1, C39.1, C40.1, IC1.1 (VDD1), IC4.8 (VCC), R30.1, R31.1, R32.1, R33.1, U3.14 (VCC), U5.1 (VCC), U6.2 (VO)
+5V_ADE: C24.1, C25.1, C26.1, C27.1, C32.1, C33.1, IC2.10 (VSEL), IC2.16 (VISO), IC3.1 (VIN), IC3.3 (EN), U2.14 (VCC)
+5V_PICO: 5V input.2, BZ1.1 (+), C28.1, C29.1, C30.2, C41.1, C42.1, C43.1, C44.1, C49.1, C50.1, C51.1, D8.2 (A), D9.1 (VDD), IC2.1 (VDD1), IC2.7 (VDDL), J3.1, U6.3 (VI)
AVDDOUT: C16.1, C17.1, U1.25 (AVDDOUT)
BUZZER: PICO.31 (GPIO26_ADC0), Q1.1 (G), R34.1
DREADY_ADE: DREADY_ADE.1, R27.1, U1.36 (CF4/*EVENT/DREADY), U2.12 (4A)
DREADY_ISO: DREADY_ISO.1, PICO.17 (GPIO13), U3.11 (4Y)
DVDDOUT: C14.1, C15.1, U1.3 (DVDDOUT)
EARTH: FB3.2, J2.1, J2.2
GND: +3V3.1 (K), C1.2, C3.2, C4.2, C6.2, C7.1, C8.2, C9.2, C10.1, C11.2, C12.2, C13.2, C14.2, C15.2, C16.2, C17.2, C18.2, C19.2, C20.2, C21.2, C22.2, C24.2, C25.2, C26.2, C27.2, C32.2, C33.2, C34.2, C35.2, CR1.3, CR2.3, CR3.3, CR4.3, DREADY.1 (K), FB3.1, GND.1, GND#2.1, IC1.11 (GND2_1), IC1.12 (VIC), IC1.19 (GND2_2), IC2.9 (GNDISO_1), IC2.15 (GNDISO_2), IC3.2 (GND), R5.1, R6.1, R7.2, R8.1, R15.1, R16.1, R17.2, R18.1, R21.2, U1.2 (DGND), U1.15 (REFGND), U1.26 (AGND), U1.28 (GND), U1.41 (EPAD), U2.1 (1OE_N), U2.4 (2OE_N), U2.7 (GND), U2.10 (3OE_N), U2.13 (4OE_N), Y1.2, Y1.4, ZX.1 (K)
GNDA: 5V input.1, C23.1, C28.2, C29.2, C30.1, C31.2, C37.2, C38.2, C39.2, C40.2, C41.2, C42.2, C43.2, C44.2, C49.2, C50.2, C51.2, D9.3 (VSS), GNDA.1, GNDA#2.1, IC1.2 (GND1_1), IC1.10 (GND1_2), IC2.2 (GND1_1), IC2.8 (GND1_2), IC4.1 (A0), IC4.2 (A1), IC4.3 (A2), IC4.4 (VSS), IC4.7 (WP), J3.5, J3.MP1, J3.MP2, J3.MP3, J3.MP4, J3.MP5, J3.MP6, PICO.3 (GND), PICO.8 (GND), PICO.13 (GND), PICO.18 (GND), PICO.23 (GND), PICO.28 (GND), PICO.33 (AGND), PICO.38 (GND), Q1.2 (S), R29.1, R34.2, SW1.1, SW2.2, U3.1 (1OE_N), U3.4 (2OE_N), U3.7 (GND), U3.10 (3OE_N), U3.13 (4OE_N), U5.2 (GND), U5.6 (SDO), U6.1 (GND)
IAN: C7.2, R13.2, U1.8 (IAN)
IAP: C6.1, R11.2, U1.7 (IAP)
IBN: C10.2, R20.2, U1.10 (IBN)
IBP: C9.1, R19.2, U1.9 (IBP)
IRQ0_ADE: IRQ0.1 (K), IRQ0_ADE.1, U1.31 (*IRQ0), U2.2 (1A)
IRQ0_ISO: IRQ0_ISO.1, PICO.14 (GPIO10), U3.3 (1Y)
IRQ1_ADE: IRQ1_ADE.1, U1.32 (*IRQ1), U2.5 (2A)
IRQ1_ISO: IRQ1_ISO.1, PICO.29 (GPIO22), U3.6 (2Y)
MISO_ADE: IC1.16 (SO), MISO_ADE.1, U1.38 (MISO)
MISO_ISO: IC1.5 (MI), MISO_ISO.1, PICO.21 (GPIO16)
MOSI_ADE: IC1.17 (SI), MOSI_ADE.1, U1.39 (MOSI)
MOSI_ISO: IC1.4 (MO), MOSI_ISO.1, PICO.25 (GPIO19)
unnamed: BZ1.2 (-), R35.1
unnamed: IRQ0.2 (A), R24.2
unnamed: IRQ1.2 (A), R25.2
unnamed: R26.2, ZX.2 (A)
unnamed: DREADY.2 (A), R27.2
unnamed: +3V3.2 (A), R28.2
unnamed: D6.1 (K), SW1.2
unnamed: D8.1 (K), PICO.39 (VSYS)
unnamed: FB1.1, R1.1
unnamed: FB2.1, R9.1
unnamed: IC2.14 (VIA), U2.3 (1Y)
unnamed: IC2.13 (VIB), U2.6 (2Y)
unnamed: IC2.12 (VIC), U2.8 (3Y)
unnamed: IC2.11 (VID), U2.11 (4Y)
unnamed: IC2.3 (VOA), U3.2 (1A)
unnamed: IC2.4 (VOB), U3.5 (2A)
unnamed: IC2.5 (VOC), U3.9 (3A)
unnamed: IC2.6 (VOD), U3.12 (4A)
unnamed: CR1.1, CR2.2, LIVE CURRENT.1, R7.1, R11.1, T1.1
unnamed: CR1.2, CR2.1, LIVE CURRENT.2, R8.2, R13.1, T1.4
unnamed: CR3.1, CR4.2, NEUTRAL CURRENT.1, R17.1, R19.1, T2.1
unnamed: CR3.2, CR4.1, NEUTRAL CURRENT.2, R18.2, R20.1, T2.4
unnamed: Q1.3 (D), R35.2
unnamed: R1.2, R2.1
unnamed: R2.2, R3.1
unnamed: R3.2, R4.1
unnamed: R9.2, R10.1
unnamed: R10.2, R12.1
unnamed: R12.2, R14.1
unnamed: C13.1, U1.29 (CLKIN), Y1.3
unnamed: C12.1, U1.30 (CLKOUT), Y1.1
unnamed: PICO.34 (GPIO28_ADC2), SW2.1
PM1_ADE: IC1.14 (VOA), PM1_ADE.1, R21.1, U1.5 (PM1)
PM1_ISO: IC1.7 (VIA), PICO.19 (GPIO14), PM1_ISO.1, R29.2
REF: C18.1, C19.1, U1.16 (REF)
RESET_ADE: C11.1, IC1.13 (VOB), R22.2, RESET_ADE.1, U1.6 (*RESET)
RESET_ISO: C36.2, D6.2 (A), D7.2 (A), IC1.8 (VIB), PICO.26 (GPIO20), R30.2, RESET_ISO.1
RESET_PICO: D7.1 (K), PICO.30 (RUN)
SCLK_ADE: IC1.18 (SCLK), SCLK_ADE.1, U1.37 (SCLK)
SCLK_ISO: IC1.3 (MCLK), PICO.24 (GPIO18), SCLK_ISO.1
SCL_PICO: IC4.6 (SCL), PICO.7 (GPIO5), R32.2, U5.3 (SCL)
SDA_PICO: IC4.5 (SDA), PICO.6 (GPIO4), R31.2, U5.4 (SDA)
SS_ADE: IC1.15 (~SSS), R23.1, SS_ADE.1, U1.40 (*SS)
SS_ISO: IC1.6 (~MSS), PICO.22 (GPIO17), R33.2, SS_ISO.1
VA: FB1.2, J1.1
VAN: C2.2, C3.1, R6.2, U1.19 (VAN)
VAP: C1.1, C2.1, R4.2, R5.2, U1.20 (VAP)
VB: FB2.2, J1.2
VBN: C5.2, C8.1, R16.2, U1.21 (VBN)
VBP: C4.1, C5.1, R14.2, R15.2, U1.22 (VBP)
WS_LED: D9.4 (DIN), PICO.12 (GPIO9)
ZX_ADE: R26.1, U1.35 (CF3/ZX), U2.9 (3A), ZX_ADE.1
ZX_ISO: PICO.16 (GPIO12), U3.8 (3Y), ZX_ISO.1

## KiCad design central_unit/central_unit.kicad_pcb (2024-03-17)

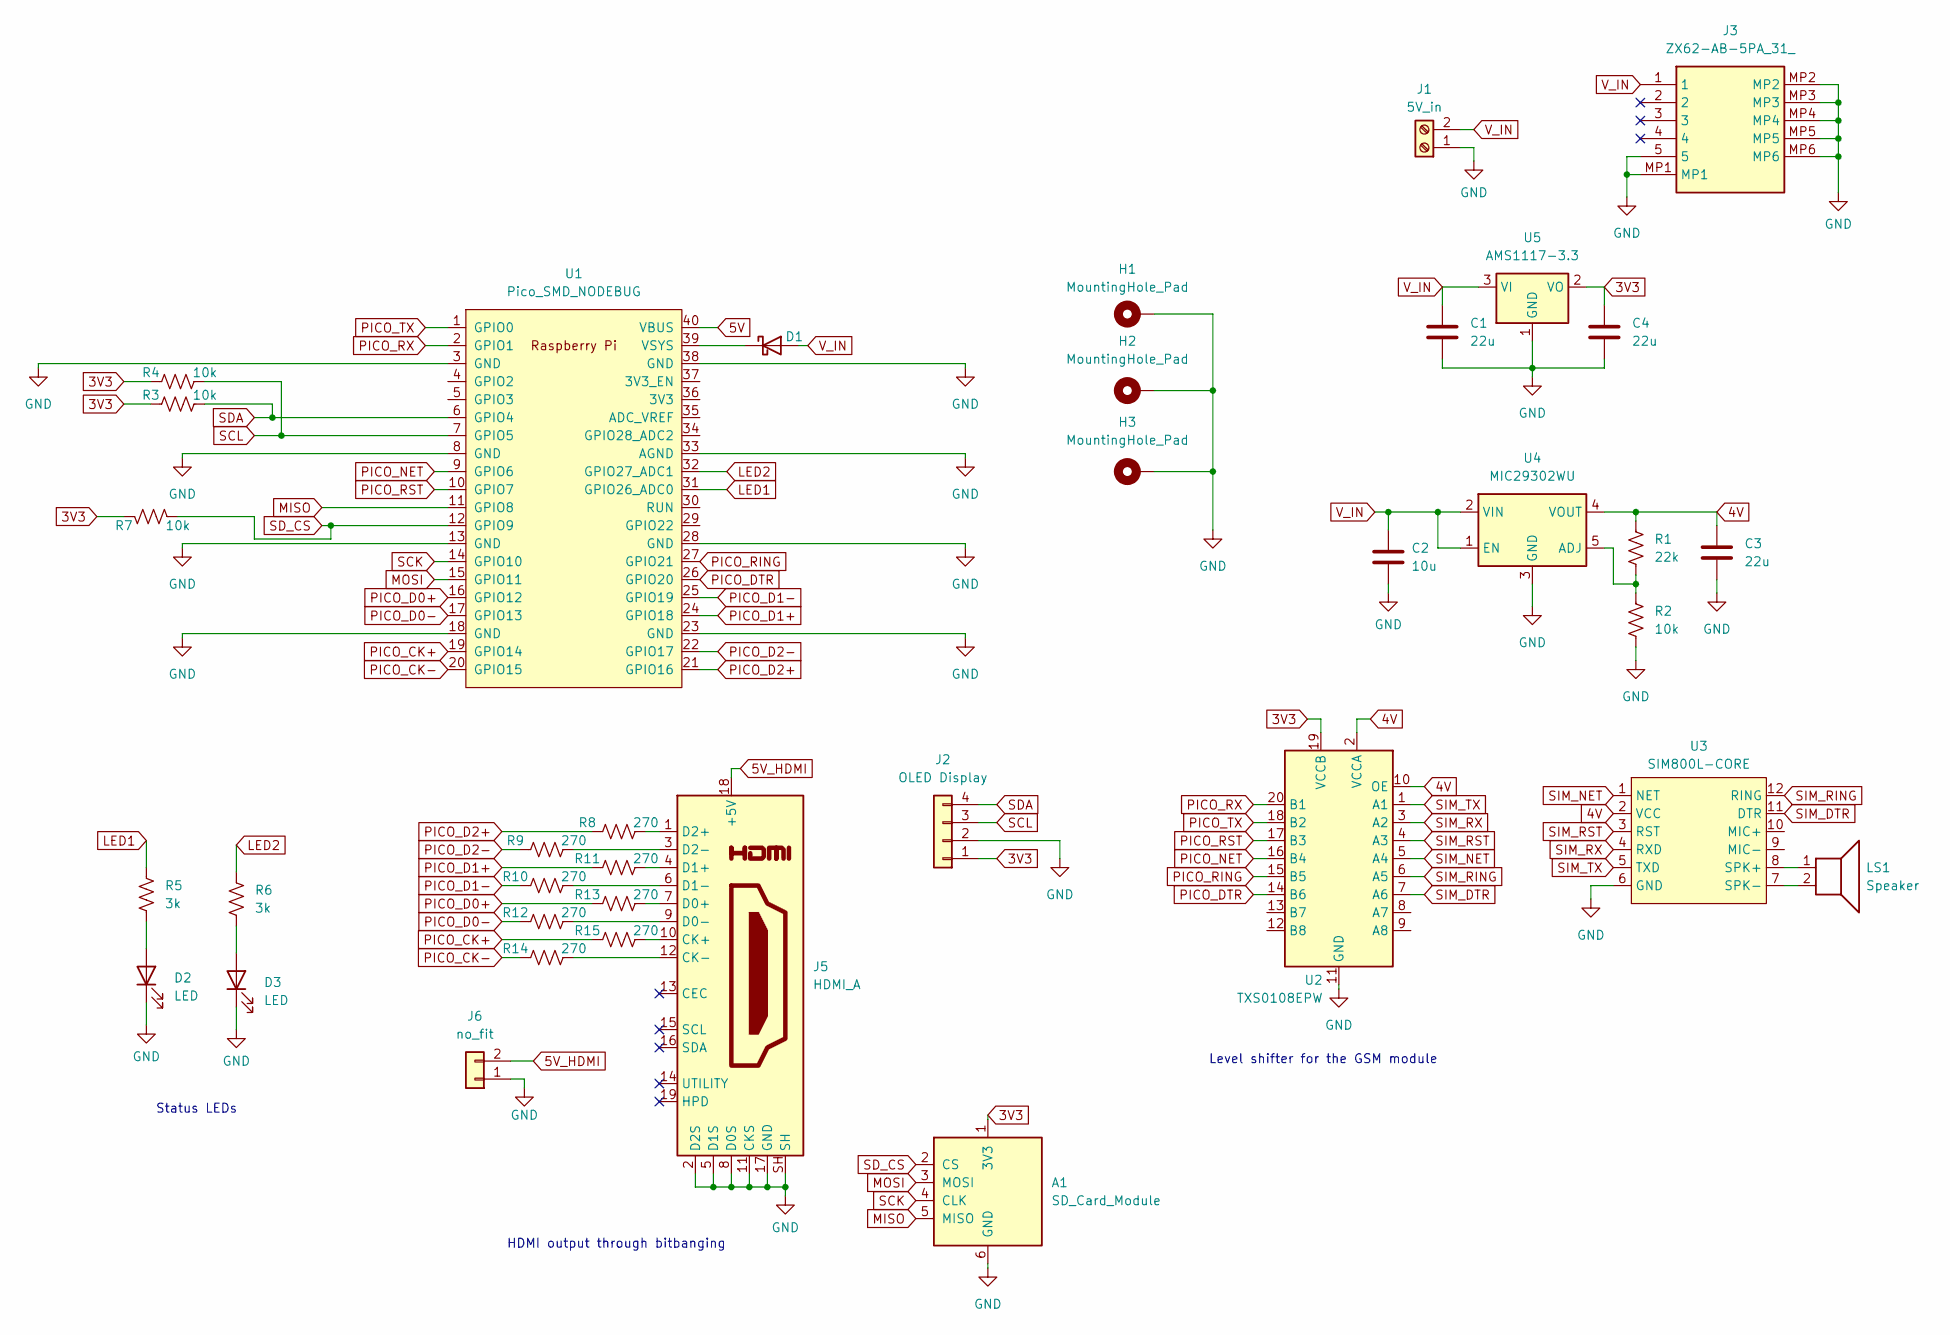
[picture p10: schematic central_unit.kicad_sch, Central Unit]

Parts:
A1: SD_Card_Module
C1, C3, C4: 22u; C_0805_2012Metric_Pad1.18x1.45mm_HandSolder
C2: 10u; C_0805_2012Metric_Pad1.18x1.45mm_HandSolder
D1: D_Schottky; D_SOD-323_HandSoldering
D2, D3: LED; LED_0603_1608Metric_Pad1.05x0.95mm_HandSolder
H1, H2, H3: MountingHole_Pad; MountingHole_3.2mm_M3_Pad_Via
J1: 5V_in; TerminalBlock_Phoenix_MKDS-1,5-2_1x02_P5.00mm_Horizontal
J2: OLED Display; 128x64OLED
J3: ZX62-AB-5PA_31_; ZX62AB5PA31; Mouser Part Number 798-ZX62-AB-5PA31
J5: HDMI_A; HDMI_A_Molex_208658-1001_Horizontal
J6: no_fit; PinHeader_1x02_P2.54mm_Vertical
LS1: Speaker; Buzzer_12x9.5RM7.6
R1: 22k; R_0805_2012Metric_Pad1.20x1.40mm_HandSolder
R2, R3, R4, R7: 10k; R_0805_2012Metric_Pad1.20x1.40mm_HandSolder
R5, R6: 3k; R_0805_2012Metric_Pad1.20x1.40mm_HandSolder
R8, R9, R10, R11, R12, R13, R14, R15: 270; R_0805_2012Metric_Pad1.20x1.40mm_HandSolder
U1: Pico_SMD_NODEBUG; RPi_Pico_SMD
U2: TXS0108EPW; TSSOP-20_4.4x6.5mm_P0.65mm
U3: SIM800L-CORE
U4: MIC29302WU; TO-263-5_TabPin3
U5: AMS1117-3.3; SOT-223-3_TabPin2

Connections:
3V3: A1.1 (3V3), C4.1, J2.1, R3.1, R4.1, R7.1, U2.19 (VCCB), U5.2 (VO)
4V: C3.1, R1.2, U2.2 (VCCA), U2.10 (OE), U3.2 (VCC), U4.4 (VOUT)
5V: U1.40 (VBUS)
5V_HDMI: J5.18 (+5V), J6.2
GND: A1.6 (GND), C1.2, C2.2, C3.2, C4.2, D2.1 (K), D3.1 (K), H1.1, H2.1, H3.1, J1.1, J2.2, J3.5, J3.MP1, J3.MP2, J3.MP3, J3.MP4, J3.MP5, J3.MP6, J5.2 (D2S), J5.5 (D1S), J5.8 (D0S), J5.11 (CKS), J5.17 (GND), J5.SH, J6.1, R2.1, U1.3 (GND), U1.8 (GND), U1.13 (GND), U1.18 (GND), U1.23 (GND), U1.28 (GND), U1.33 (AGND), U1.38 (GND), U2.11 (GND), U3.6 (GND), U4.3 (GND), U5.1 (GND)
LED1: R5.1, U1.31 (GPIO26_ADC0)
LED2: R6.1, U1.32 (GPIO27_ADC1)
MISO: A1.5 (MISO), U1.11 (GPIO8)
MOSI: A1.3 (MOSI), U1.15 (GPIO11)
unnamed: D1.1 (K), U1.39 (VSYS)
unnamed: D2.2 (A), R5.2
unnamed: D3.2 (A), R6.2
unnamed: J5.10 (CK+), R15.2
unnamed: J5.12 (CK-), R14.2
unnamed: J5.7 (D0+), R13.2
unnamed: J5.9 (D0-), R12.2
unnamed: J5.4 (D1+), R11.2
unnamed: J5.6 (D1-), R10.2
unnamed: J5.1 (D2+), R8.2
unnamed: J5.3 (D2-), R9.2
unnamed: LS1.1, U3.8 (SPK+)
unnamed: LS1.2, U3.7 (SPK-)
unnamed: R1.1, R2.2, U4.5 (ADJ)
PICO_CK+: R15.1, U1.19 (GPIO14)
PICO_CK-: R14.1, U1.20 (GPIO15)
PICO_D0+: R13.1, U1.16 (GPIO12)
PICO_D0-: R12.1, U1.17 (GPIO13)
PICO_D1+: R11.1, U1.24 (GPIO18)
PICO_D1-: R10.1, U1.25 (GPIO19)
PICO_D2+: R8.1, U1.21 (GPIO16)
PICO_D2-: R9.1, U1.22 (GPIO17)
PICO_DTR: U1.26 (GPIO20), U2.14 (B6)
PICO_NET: U1.9 (GPIO6), U2.16 (B4)
PICO_RING: U1.27 (GPIO21), U2.15 (B5)
PICO_RST: U1.10 (GPIO7), U2.17 (B3)
PICO_RX: U1.2 (GPIO1), U2.20 (B1)
PICO_TX: U1.1 (GPIO0), U2.18 (B2)
SCK: A1.4 (CLK), U1.14 (GPIO10)
SCL: J2.3, R4.2, U1.7 (GPIO5)
SDA: J2.4, R3.2, U1.6 (GPIO4)
SD_CS: A1.2 (CS), R7.2, U1.12 (GPIO9)
SIM_DTR: U2.7 (A6), U3.11 (DTR)
SIM_NET: U2.5 (A4), U3.1 (NET)
SIM_RING: U2.6 (A5), U3.12 (RING)
SIM_RST: U2.4 (A3), U3.3 (RST)
SIM_RX: U2.3 (A2), U3.4 (RXD)
SIM_TX: U2.1 (A1), U3.5 (TXD)
V_IN: C1.1, C2.1, D1.2 (A), J1.2, J3.1, U4.1 (EN), U4.2 (VIN), U5.3 (VI)

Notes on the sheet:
Level shifter for the GSM module
Status LEDs
HDMI output through bitbanging

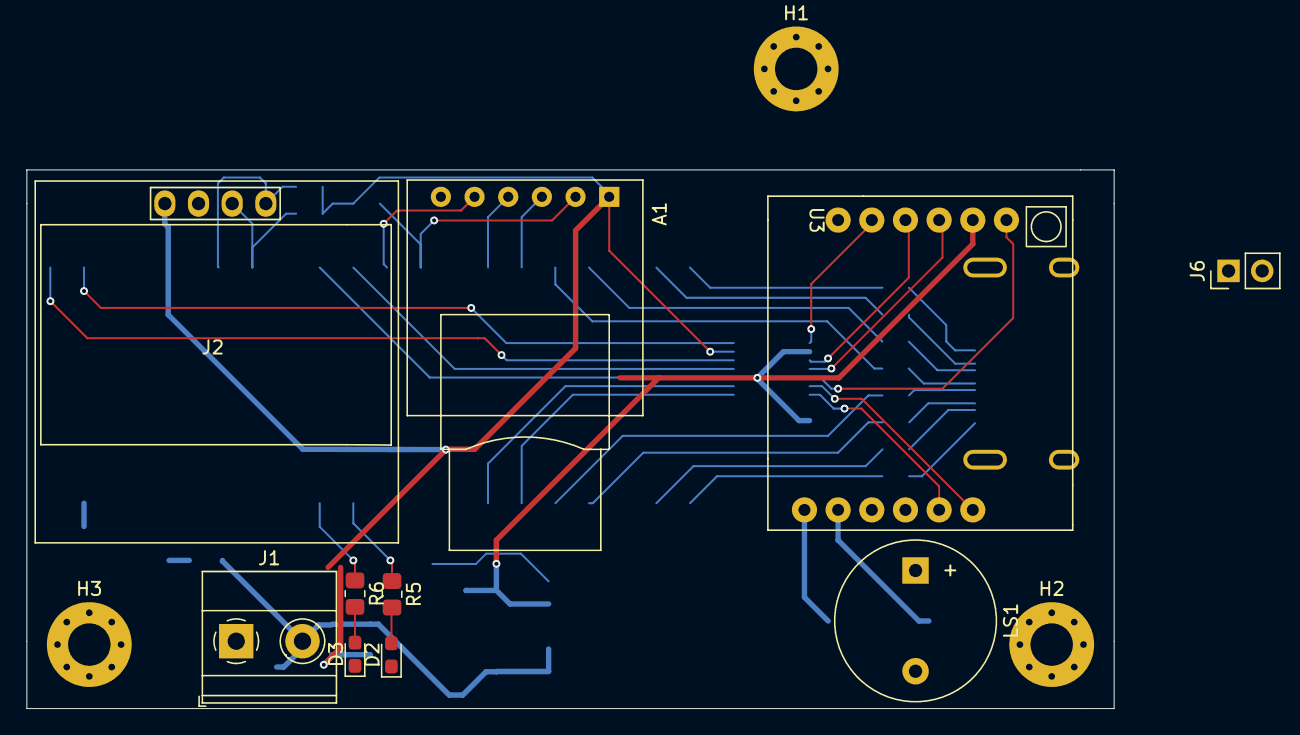
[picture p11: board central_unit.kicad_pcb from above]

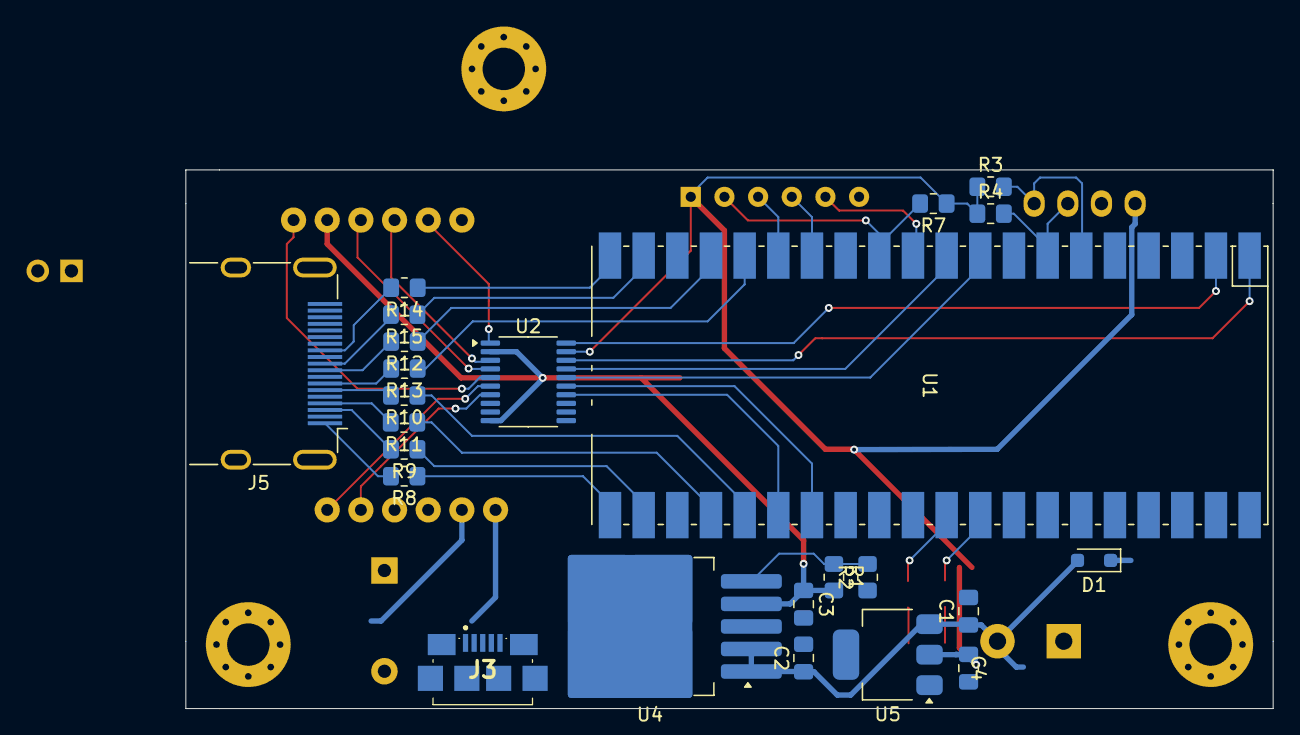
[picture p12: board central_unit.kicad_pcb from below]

Board: 2 copper layers, 82.0 x 40.6 mm, 37 parts (24 on the bottom side), 47 nets.

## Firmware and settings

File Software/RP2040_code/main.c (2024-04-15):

#include <stdio.h>
#include <string.h>
#include "pico/stdlib.h"
#include "pico/cyw43_arch.h"
#include "pico/multicore.h"
#include "hardware/spi.h"
#include "hardware/i2c.h"
#include "hardware/gpio.h"
#include "hardware/vreg.h"
#include "hardware/clocks.h"
#include "hardware/pio.h"
#include "ADE9000API_RP2040.h"
#include "lwipopts.h"
#include "bme280.h"
#include "blocking.h"
#include "flash_utils.h"
#include "tcp_server.h"
#include "ws2812.pio.h"

//hellooooo
#define DELAY_CONN 10000
#define DELAY_NOCONN 2000

/* NEOPIXEL DEFINITIONS */
#define IS_RGBW true
#define NUM_PIXELS 1
#define WS2812_PIN 9

/* ADE9000 POWER QUALITY INTERRUPT DEFINITIONS */
#define DIP_LEVEL 5.0 // Dip threshold. Must be float
#define SWELL_LEVEL 9.0 // Swell threshold. Must be float
#define DIP_SWELL_CYCLE 100 // Number of halfcycles of sustained dip or swell before interrupt
#define OVERCURRENT_LEVEL 1.0 //Overcurrent threshold. Must be float 
#define MASK1_USER (1 << 23  | 1 << 20 | 1 << 17) // Enable dip_A, swell_A, and overcurrent detection
#define EVENTMASK_USER (1 << 3 | 1 << 0) // Enable events for dip_A, swell_A
#define CONFIG3_USER (1 << 12 | 1 << 2) // Enable overcurrent detection and peak measurement on channel A 
uint32_t event_start = 0;
uint32_t event_end = 0;
uint32_t event_status;

/* SPI DEFINITIONS */
#define SPI_SPEED 5000000  //10 MHz 
#define SCK_PIN 18
#define MOSI_PIN 19
#define MISO_PIN 16
#define CS_PIN 17

/* I2C DEFINITIONS */
#define SDA_PIN 4
#define SCL_PIN 5
#define I2C_SPEED 100000 // 100 kHz

/* GPIO DEFINITIONS */
#define RESETADE_PIN 20
#define IRQ0_PIN 10
#define IRQ1_PIN 22
#define ZX_PIN 12
#define DREADY_PIN 13
#define PM1_PIN 14
#define BUZZER 26

/* FLASH CONFIGURATION ADDRESSES */
#define ADDR_PERSISTENT getAddressPersistent()

/* WIFI DETAILS */
#define WIFI_SSID "Shobhit"
#define WIFI_PASSWORD "nananana"

/* MULTICORE DEFINITIONS */
/*#define START_LOGGING 1     // signal for first core to start data logging. Make sure its a low number
#define SENSOR_EMERGENCY 2 */ 
typedef struct {            // to faciliate sensor data transfer 
    uint32_t time;
    float VArms;
    float VBrms;
    float IArms;
    float IBrms;
    float PowerA;
    float PowerB;
    float PfA;
    float PfB;
    float freqA;
    float freqB;
    float Temperature;
    float Pressure;
    float Humidity;
    uint32_t emergency;     // From LSB: (DipA)(DipB)(SwellA)(SwellB)(OIA)(OIB)(Temp)(Pressure)(Humidity)(NoLoadA)(NoLoadB)
    int32_t waveform_buffer1[128*8]; // Eight consecutive readings of the waveform buffer
    //int32_t waveform_buffer2[WFB_ELEMENT_ARRAY_SIZE];
    //int32_t waveform_buffer3[WFB_ELEMENT_ARRAY_SIZE];
    //int32_t waveform_buffer4[WFB_ELEMENT_ARRAY_SIZE];
    int16_t resampled_VA[512];
    int16_t resampled_IA[512];
    int16_t resampled_VB[512];
    int16_t resampled_IB[512];
} sensorData;

#define DATA_SIZE sizeof(sensorData)

// Data structures and sensor objects
ResampledWfbData resampledData; // Resampled Data
WaveformData FixedWaveformData; // Fized rate data from waveform
ActivePowerRegs powerRegs;     // Declare powerRegs of type ActivePowerRegs to store Active Power Register data
CurrentRMSRegs curntRMSRegs;   //Current RMS
VoltageRMSRegs vltgRMSRegs;    //Voltage RMS
PeriodRegs freqData;            // Frequency of channels
PowerFactorRegs pfData;         // Power factors
VoltageTHDRegs voltageTHDRegsnValues; //Voltage THD
bme280_t bme280; //BME sensor struct
bme280_reading_t r; //BME data struct
sensorData data; // struct holding all sensor data;

// Ports
spi_inst_t *spi = spi0;
i2c_inst_t *i2c = i2c0;
PIO pio = pio0;
int sm = 0;

/*void core0_sio_irq() {
    // Just record the latest entry
    while (multicore_fifo_rvalid())
        uint32_t core0_rx_val = multicore_fifo_pop_blocking();

    multicore_fifo_clear_irq();
}

void core1_sio_irq() {
    // Just record the latest entry
    while (multicore_fifo_rvalid())
        core1_rx_val = multicore_fifo_pop_blocking();

    multicore_fifo_clear_irq();
}*/

uint32_t count = 0;
uint32_t curr_time = 0;

static inline void put_pixel(uint32_t pixel_grb) {
    pio_sm_put_blocking(pio0, 0, pixel_grb << 8u);
}

static inline uint32_t urgb_u32(uint8_t r, uint8_t g, uint8_t b) {
    return
            ((uint32_t) (r) << 8) |
            ((uint32_t) (g) << 16) |
            (uint32_t) (b);
}

bool reserved_addr(uint8_t addr) {
    return (addr & 0x78) == 0 || (addr & 0x78) == 0x78;
}

static int scan_result(void *env, const cyw43_ev_scan_result_t *result) {
    if (result) {
        printf("ssid: %-32s rssi: %4d chan: %3d mac: %02x:%02x:%02x:%02x:%02x:%02x sec: %u\n",
            result->ssid, result->rssi, result->channel,
            result->bssid[0], result->bssid[1], result->bssid[2], result->bssid[3], result->bssid[4], result->bssid[5],
            result->auth_mode);
    }
    return 0;
}

/* Read normal data */
void getData () {
    count += 1;
    curr_time = to_ms_since_boot(get_absolute_time());

    // Read from BME280
    bme280_read(&bme280, &r);

    //Template to read Power registers from ADE9000 and store data in Arduino MCU
    ReadActivePowerRegs(spi, CS_PIN, &powerRegs);
    ReadCurrentRMSRegs(spi, CS_PIN, &curntRMSRegs);
    ReadVoltageRMSRegs(spi, CS_PIN, &vltgRMSRegs);
    ReadPowerFactorRegsnValues(spi, CS_PIN, &pfData);
    ReadPeriodRegsnValues(spi, CS_PIN, &freqData);

    // Update data struct
    data.time = curr_time;
    data.VArms = voltage_gain*(float)vltgRMSRegs.VoltageRMSReg_A;
    data.VBrms = voltage_gain*(float)vltgRMSRegs.VoltageRMSReg_B;
    data.IArms = current_gain*(float)curntRMSRegs.CurrentRMSReg_A;
    data.IBrms = current_gain*(float)curntRMSRegs.CurrentRMSReg_B;
    data.PowerA = power_gain*(float)powerRegs.ActivePowerReg_A;
    data.PowerB = power_gain*(float)powerRegs.ActivePowerReg_B;
    data.PfA = pfData.PowerFactorValue_A;
    data.PfB = pfData.PowerFactorValue_B;
    data.freqA = freqData.FrequencyValue_A;
    data.freqB = freqData.FrequencyValue_B;
    data.Temperature = r.temperature;
    data.Pressure = r.pressure;
    data.Humidity = r.humidity;
    data.emergency = 0;
}

/*Read Waveform data in fixed data rate mode*/
void getWaveForm() {

    uint32_t mask0_init;
    uint32_t status0_init;
    uint32_t last_filled_addr;

    char count = 0;

    // TODO: MAKE CONTINUOUS SAMPLING
    SPI_Write_16(spi, CS_PIN, ADDR_WFB_CFG, 0x1000); // Stop waveform sampling

    mask0_init = SPI_Read_32(spi, CS_PIN, ADDR_MASK0);
    status0_init = SPI_Read_32(spi, CS_PIN, ADDR_STATUS0);
    printf("STATUS0 before waveform read: %u\n", status0_init);
    printf("MASK0 before waveform read: %u\n", mask0_init);
    SPI_Write_32(spi, CS_PIN, ADDR_STATUS0, 0); // Clear interrupts
    SPI_Write_32(spi, CS_PIN, ADDR_MASK0, 0);
    sleep_ms(10);
    SPI_Write_32(spi, CS_PIN, ADDR_MASK0, (1 << 17)); // Enable page full interrupt for waveform buffer
    SPI_Write_16(spi, CS_PIN, ADDR_WFB_PG_IRQEN, 0x8080); // Enable interrupts on page 7 and 15

    SPI_Write_16(spi, CS_PIN, ADDR_RUN,ADE9000_RUN_ON); //DSP ON
    //SPI_Write_16(spi, CS_PIN, ADDR_WFB_CFG, 0x1220); // Store the fixed data rate values from sinc4 + LPF
    //SPI_Write_16(spi, CS_PIN, ADDR_WFB_CFG, 0x1230); // Start sampling
    SPI_Write_16(spi, CS_PIN, ADDR_WFB_CFG, 0x03F0); // Read continuous fixed rate data from all channels except IN

    while (count < 8) {
        if ((SPI_Read_32(spi, CS_PIN, ADDR_STATUS0) & (1 << 17))) { // Trigger hua
            SPI_Write_16(spi, CS_PIN, ADDR_WFB_CFG, 0x1000); // STOP
            printf("STATUS0: %u\n", SPI_Read_32(spi, CS_PIN, ADDR_STATUS0));
            last_filled_addr = (SPI_Read_32(spi, CS_PIN, ADDR_WFB_TRG_STAT) & 0xF000) >> 12;
            printf("Last filled page is %u\n", last_filled_addr);
            if (last_filled_addr == 15) { // last page filled is page 15
                SPI_Burst_Read_Fixed_Rate(spi, CS_PIN, 0xC00, 128, &FixedWaveformData);
                printf("Read from page 8-15\n");
            } else { // last page filled is 15
                SPI_Burst_Read_Fixed_Rate(spi, CS_PIN, 0x800, 128, &FixedWaveformData);
                printf("Read from page 0-7\n");
            }
            memcpy(&(data.waveform_buffer1[128*count]), &(FixedWaveformData.VA_waveform[0]), 128*4);
            SPI_Write_32(spi, CS_PIN, ADDR_STATUS0, 0); // clear interrupt
            SPI_Write_16(spi, CS_PIN, ADDR_WFB_CFG, 0x03F0); // start sampling again
            count++;
        }
        sleep_ms(1);
    }

    SPI_Write_16(spi, CS_PIN, ADDR_WFB_CFG, 0x1000); // Stop waveform sampling
    SPI_Write_32(spi, CS_PIN, ADDR_STATUS0, 0x00000000); // Clear interrupts
    SPI_Write_32(spi, CS_PIN, ADDR_MASK0, mask0_init); // Restore mask0
    printf("MASK0 after waveform read: %u\n", SPI_Read_32(spi, CS_PIN, ADDR_MASK0));
}

/*Read Waveform data in fixed data rate mode*/
void getResampledWaveform() {
    SPI_Write_16(spi, CS_PIN, ADDR_WFB_CFG, 0x1000); // Stop waveform sampling
    SPI_Write_16(spi, CS_PIN, ADDR_RUN,ADE9000_RUN_ON); //DSP ON
    SPI_Write_16(spi, CS_PIN, ADDR_WFB_CFG, 0x1010);  //Start sampling
    sleep_ms(200); // Time to fill waveform bufer
    SPI_Burst_Read_Resampled_Wfb(spi, CS_PIN, 0x800, 512, &resampledData);
    SPI_Write_16(spi, CS_PIN, ADDR_WFB_CFG, 0x1000); // Stop waveform sampling

    // update data struct
    memcpy(&(data.resampled_IA[0]), &(resampledData.IA_Resampled[0]), 1024);
    memcpy(&(data.resampled_VA[0]), &(resampledData.VA_Resampled[0]), 1024);
    memcpy(&(data.resampled_IB[0]), &(resampledData.IB_Resampled[0]), 1024);
    memcpy(&(data.resampled_VB[0]), &(resampledData.VB_Resampled[0]), 1024);
}

void printWaveformBuffer() {
    printf("\n==========Waveform buffer============\n");
    uint32_t temp;
    for(temp=0;temp<512;temp++)
        {
        printf("VA: %d\n", data.resampled_VA[temp]);
        //printf("IA: %f\n", resampledData.IA_Resampled[temp]);
        //printf("VB: %d\n", resampledData.VB_Resampled[temp]);
        //printf("IB: %d\n", resampledData.IB_Resampled[temp]);
        //printf("VC: %d\n", resampledData.VC_Resampled[temp]);
        //printf("IC: %d\n", resampledData.IC_Resampled[temp]);
        //printf("IN: %d\n", resampledData.IN_Resampled[temp]);
    } 
    printf("====================================\n");
}

void printData () {
    printf("===================================\n");
    printf("MEASURE COUNT: %d\n", count);
    printf("Current time: %d\n", curr_time);
    printf("Temperature: %.2f°C\nPressure: %.2f Pa\nHumidity: %.2f%%\n",
        data.Temperature, data.Pressure, data.Humidity);
    printf("-----------------------------------\n");
    printf("VA_rms: %f\n", data.VArms);
    printf("IA_rms: %f\n", data.IArms);
    printf("freq_A: %f\n", data.freqA);        
    printf("Power factor A: %f\n", data.PfA);
    printf("Power in A channel (WATT): %f\n", data.PowerA);
    printf("VB_rms: %f\n", data.VBrms);
    printf("IB_rms: %f\n", data.IBrms);
    printf("freq_B: %f\n", data.freqB);        
    printf("Power factor B: %f\n", data.PfB);
    printf("Power in B channel (WATT): %f\n", data.PowerB);
    printf("VERSION (should be 254): %d\n", SPI_Read_16(spi, CS_PIN, ADDR_VERSION));
    printf("RUN REGISTER: %d\n", SPI_Read_16(spi, CS_PIN, ADDR_RUN));
    printf("===================================\n");
    
    printf("Size of structure: %d bytes\n", DATA_SIZE);
    printf("\n");
}

void irq0_callback(uint gpio, uint32_t events) {
    printf("Interrupt at IRQ0 at GPIO %u!\n", gpio);
    // Read the STATUS0 register
    printf("STATUS0: %u\n", SPI_Read_32(spi, CS_PIN, ADDR_STATUS0));
}

void irq1_callback(uint gpio, uint32_t events) {
    printf("Interrupt at IRQ1 at GPIO %u!\n", gpio);
    // Read the STATUS1 register
    uint32_t status1 = SPI_Read_32(spi, CS_PIN, ADDR_STATUS1);
    printf("STATUS1: %u\n", status1);

    if (status1 & (1 << 23)) { // DIP in channel A
        // Read the peak voltage
        double peak = (double)(SPI_Read_32(spi, CS_PIN, ADDR_VPEAK) & ((1 << 24) - 1))*32.0/voltage_gain;
        status1 ^= (1 << 23);
        if (data.emergency & (1 << 0)) {
            printf("Dip event over in channel A\n");
            printf("Peak voltage during dip: %f\n", peak);
        } else {
            data.emergency |= (1 << 0);
            printf("Dip event started in channel A\n");  
            printf("Peak voltage before dip: %f\n", peak);
        }
    }

    if (status1 & (1 << 20)) { // Swell in channel A
        // Read the peak voltage
        double peak = (double)(SPI_Read_32(spi, CS_PIN, ADDR_VPEAK) & ((1 << 24) - 1))*32.0/voltage_gain;
        status1 ^= (1 << 20);
        if (data.emergency & (1 << 2)) {
            printf("Swell event over in channel A\n");
            printf("Peak voltage during swell: %f\n", peak);
        } else {
            data.emergency |= (1 << 2);
            printf("Swell event started in channel A\n");  
            printf("Peak voltage before swell: %f\n", peak);
        }
    }

    if (status1 & (1 << 17)) { // Overcurrent in channel A
        // Read the peak current
        double peak = (double)(SPI_Read_32(spi, CS_PIN, ADDR_IPEAK) & ((1 << 24) - 1))*32.0/current_gain;
        status1 ^= (1 << 17);
        if (data.emergency & (1 << 4)) {
            printf("Overcurrent event over in channel A\n");
            printf("Peak current during overcurrent: %f\n", peak);
        } else {
            data.emergency |= (1 << 4);
            printf("Overcurrent event started in channel A\n");  
            printf("Peak current before overcurrent: %f\n", peak);
        }
    }

    // Clear the status register to stop the interrupt
    SPI_Write_32(spi, CS_PIN, ADDR_STATUS1, status1);

}

void event_callback(uint gpio, uint32_t events) {
    printf("Event interrupt triggered at GPIO %u!\n", gpio);
    // Read the event status register
    event_status = SPI_Read_32(spi, CS_PIN, ADDR_EVENT_STATUS);
    printf("Event status register: %u\n", event_status);

    if (gpio_get(gpio)) { // event started
        event_start = to_ms_since_boot(get_absolute_time());

        if (event_status & (1 << 0)) {
            printf("We are in a dip event\n");
        }

        if (event_status & (1 << 3)) {
            printf("We are in a swell event\n");
        }
    } else { // event ended
        event_end = to_ms_since_boot(get_absolute_time());
        printf("Event ended after time: %u ms\n", event_end - event_start);
    }
    
}

void dummy_callback(uint gpio, uint32_t events) {
    printf("GPIO TOGGLE ON %u\n", gpio);
    printf("EVENTS: %u\n", events);
}

int main() {

    // Initialize chosen serial port (USB for now) and WiFi
    stdio_init_all();

    // Start the statemachine or the neopixel
    uint offset = pio_add_program(pio, &ws2812_program);
    ws2812_program_init(pio, sm, offset, WS2812_PIN, 800000, IS_RGBW);
    put_pixel(urgb_u32(0,0,0x80)); // light blue?

    //sleep_ms(4000);
    //printf("ENTERING PROGRAM\n");

    if (cyw43_arch_init()) {
        printf("Wifi init failed");
        return -1;
    }

    cyw43_arch_enable_sta_mode();

    // Initialize Ports
    spi_init(spi, SPI_SPEED);
    i2c_init(i2c, I2C_SPEED);

    // Set SPI format. We set it to transfer 16 bits every transfer. SPI MODE 0
    spi_set_format( spi,   // SPI instance
                    16,     // Number of bits per transfer
                    SPI_CPOL_0,      // Polarity (CPOL)
                    SPI_CPHA_0,      // Phase (CPHA)
                    SPI_MSB_FIRST);

    // Initialize SPI pins
    gpio_set_function(SCK_PIN, GPIO_FUNC_SPI);
    gpio_set_function(MOSI_PIN, GPIO_FUNC_SPI);
    gpio_set_function(MISO_PIN, GPIO_FUNC_SPI);

    //Initialize I2C pins
    gpio_set_function(SDA_PIN, GPIO_FUNC_I2C);
    gpio_set_function(SCL_PIN, GPIO_FUNC_I2C);
    gpio_pull_up(SDA_PIN);
    gpio_pull_up(SCL_PIN);

    // Initialize interrupt pins. They go low when active so we will only monitor falling edge
    // gpio_set_irq_enabled_with_callback(IRQ0_PIN,  GPIO_IRQ_EDGE_FALL, true, &irq0_callback);
    // gpio_set_irq_enabled_with_callback(IRQ1_PIN,  GPIO_IRQ_EDGE_FALL, true, &irq1_callback);
    // Initialize event pin interrupts. Both edges to measure time of event 
    //gpio_init(DREADY_PIN);
    //gpio_set_dir(DREADY_PIN, GPIO_IN);
    //gpio_set_irq_enabled_with_callback(MISO_PIN, GPIO_IRQ_EDGE_RISE, true, &dummy_callback);

    // Initialize other pins 
    gpio_init(PM1_PIN);
    gpio_init(ZX_PIN);
    gpio_init(RESETADE_PIN);
    gpio_init(CS_PIN);
    gpio_set_dir(PM1_PIN, GPIO_OUT);
    gpio_set_dir(RESETADE_PIN, GPIO_OUT);
    gpio_set_dir(ZX_PIN, GPIO_IN);
    gpio_set_dir(CS_PIN, GPIO_OUT);

    gpio_put(CS_PIN, 1);
    gpio_put(PM1_PIN, 0); // start in normal power mode
    gpio_put(RESETADE_PIN, 1); // reset is active low

    sleep_ms(1000);

    // Check if flash reservation works
    printf("\nPersistent Flash (ROM) address at: %d\n\n", ADDR_PERSISTENT);

    // Perform i2c bus scan to see if BME280 and EEPROM are connected
    /*printf("\nI2C Bus Scan\n");
    printf("   0  1  2  3  4  5  6  7  8  9  A  B  C  D  E  F\n");

    for (int addr = 0; addr < (1 << 7); ++addr) {
        if (addr % 16 == 0) {
            printf("%02x ", addr);
        }

        // Perform a 1-byte dummy read from the probe address. If a slave
        // acknowledges this address, the function returns the number of bytes
        // transferred. If the address byte is ignored, the function returns
        // -1.

        // Skip over any reserved addresses.
        int ret;
        uint8_t rxdata;
        if (reserved_addr(addr))
            ret = PICO_ERROR_GENERIC;
        else
            ret = i2c_read_timeout_us(i2c, addr, &rxdata, 1, false, 10000);

        printf(ret < 0 ? "." : "@");
        printf(addr % 16 == 15 ? "\n" : "  ");
    }
    printf("Done.\n\n");*/

    /*absolute_time_t scan_time = nil_time;
    bool scan_in_progress = false;

    if (absolute_time_diff_us(get_absolute_time(), scan_time) < 0) {
        if (!scan_in_progress) {
            cyw43_wifi_scan_options_t scan_options = {0};
            int err = cyw43_wifi_scan(&cyw43_state, &scan_options, NULL, scan_result);
            if (err == 0) {
                printf("\nPerforming wifi scan\n");
                scan_in_progress = true;
            } else {
                printf("Failed to start scan: %d\n", err);
                scan_time = make_timeout_time_ms(10000); // wait 10s and scan again
            }
        } else if (!cyw43_wifi_scan_active(&cyw43_state)) {
            scan_time = make_timeout_time_ms(10000); // wait 10s and scan again
            scan_in_progress = false; 
        }
    }

    sleep_ms(2000); // wait for scan results to arrive
    */

   // print DEBUG info for the spi bus
    /*printf("Baudrate: %d\n", spi_get_baudrate(spi));
    printf("Instance number: %d\n", spi_get_index(spi));
    printf("SPI device writeable? %s\n", spi_is_writable(spi) ? "True" : "False");
    printf("SPI device readable? %s\n", spi_is_readable(spi)? "True": "False");
    printf("ADDRESS: %d\n", SPI_Read_16(spi, CS_PIN, ADDR_VERSION));
    printf("\n");*/

    /* PERFORM ADE9000 CONFIGURATIONS HERE. LIKE THE INIT ADE9000 FUNCTION IDK */
    printf("Reset cycle for the ADE9000\n");
    resetADE(RESETADE_PIN);
    sleep_ms(200);
    SetupADE9000(spi, CS_PIN);
    sleep_ms(300);

    // Workaround: perform throw-away read to make SCK idle high. idk, just copied
    printf("Initial VERSION (Should be 254): %d\n", SPI_Read_16(spi, CS_PIN, ADDR_VERSION));
    printf("PART ID (Should be 1048576): %u\n", SPI_Read_32(spi, CS_PIN, ADDR_PARTID) & (1 << 20));
    //printf("Initial VERSION2: %d\n", SPI_Read_16(spi, CS_PIN, ADDR_VERSION2));
    //printf("Initial VERSION: %d\n", SPI_Read_16(spi, CS_PIN, ADDR_VERSION));
    printf("Initial STATUS1: %d\n", SPI_Read_16(spi, CS_PIN, ADDR_STATUS1));

    //SPI_Write_32(spi,CS_PIN, ADDR_STATUS0, 0xFFFFFFFF);
    //SPI_Write_32(spi,CS_PIN, ADDR_STATUS1, 0xFFFFFFFF);

    /* BME280 configs */
    bme280_init_struct(&bme280, i2c, 0x76, &pico_callbacks_blocking);
    bme280_init(&bme280);
    printf("BME280 config done!\n");

    sleep_ms(1000);

    put_pixel(urgb_u32(80, 16, 120)); // purple

    // connect to the specified network
    for (int i = 0; i<3; ++i) {
    printf("\nConnect attempt %d to %s\n", i, WIFI_SSID);
        if (cyw43_arch_wifi_connect_timeout_ms(WIFI_SSID, WIFI_PASSWORD, CYW43_AUTH_WPA2_AES_PSK, 30000)) {
            printf("failed to connect using {%s, %s}\n", WIFI_SSID, WIFI_PASSWORD);
            if (i == 2) {
                printf("Giving up now\n");
                return -1;
            }
            printf("Retrying...\n");
        } else {
            printf("Connected to %s\n", WIFI_SSID);
            break;
        }
        sleep_ms(1000);
    }


    /* Set up the sensing unit as a TCP server */
    TCP_SERVER_T *state = tcp_server_init(); // Get new server struct
    if (!state) { return -1;}
    if (!tcp_server_open(state, TCP_PORT)) { // Open the server to connections and wait for someone to connect
        printf("\nFailed to open TCP server. Exiting program\n");
        return -1;
    }
    printf("Waiting for a connection...\n\n");
    tcp_accept(state->server_pcb, tcp_server_accept); // tcp_server_accept will assign all callbacks
                                                      // once the connection is made
    
    // Wait before taking measurements
    sleep_ms(1000);

    // Set the voltage swell and dip thresholds
    //SPI_Write_32(spi, CS_PIN, ADDR_DIP_LVL, (uint32_t)DIP_LEVEL/voltage_gain);
    //SPI_Write_32(spi, CS_PIN, ADDR_SWELL_LVL, (uint32_t)SWELL_LEVEL/voltage_gain);
    //SPI_Write_16(spi, CS_PIN, ADDR_DIP_CYC, (uint16_t)DIP_SWELL_CYCLE);
    //SPI_Write_16(spi, CS_PIN, ADDR_SWELL_CYC, (uint16_t)DIP_SWELL_CYCLE);
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

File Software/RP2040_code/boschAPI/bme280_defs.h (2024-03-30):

/**
* Copyright (c) 2020 Bosch Sensortec GmbH. All rights reserved.
*
* BSD-3-Clause
*
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
* 1. Redistributions of source code must retain the above copyright
*    notice, this list of conditions and the following disclaimer.
*
* 2. Redistributions in binary form must reproduce the above copyright
*    notice, this list of conditions and the following disclaimer in the
*    documentation and/or other materials provided with the distribution.
*
* 3. Neither the name of the copyright holder nor the names of its
*    contributors may be used to endorse or promote products derived from
*    this software without specific prior written permission.
*
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
* @file       bme280_defs.h
* @date       2020-12-17
* @version    v3.5.1
*
*/
#include "pico/stdlib.h"


#ifndef _BME280_DEFS_H
#define _BME280_DEFS_H

/********************************************************/
/*! @name       Common macros               */
/********************************************************/

#if !defined(UINT8_C) && !defined(INT8_C)
#define INT8_C(x)    S8_C(x)
#define UINT8_C(x)   U8_C(x)
#endif

#if !defined(UINT16_C) && !defined(INT16_C)
#define INT16_C(x)   S16_C(x)
#define UINT16_C(x)  U16_C(x)
#endif

#if !defined(INT32_C) && !defined(UINT32_C)
#define INT32_C(x)   S32_C(x)
#define UINT32_C(x)  U32_C(x)
#endif

#if !defined(INT64_C) && !defined(UINT64_C)
#define INT64_C(x)   S64_C(x)
#define UINT64_C(x)  U64_C(x)
#endif

/**@}*/
/**\name C standard macros */
#ifndef NULL
#ifdef __cplusplus
#define NULL         0
#else
#define NULL         ((void *) 0)
#endif
#endif

/******************************************************************************/
/*! @name        Compiler switch macros Definitions                */
/******************************************************************************/
#ifndef BME280_64BIT_ENABLE /*< Check if 64-bit integer (using BME280_64BIT_ENABLE) is enabled */
#ifndef BME280_32BIT_ENABLE /*< Check if 32-bit integer (using BME280_32BIT_ENABLE) is enabled */
#ifndef BME280_DOUBLE_ENABLE /*< If any of the integer data types not enabled then enable BME280_DOUBLE_ENABLE */
#define BME280_DOUBLE_ENABLE
#endif
#endif
#endif

/******************************************************************************/
/*! @name        General Macro Definitions                */
/******************************************************************************/
#ifndef TRUE
#define TRUE                                      UINT8_C(1)
#endif
#ifndef FALSE
#define FALSE                                     UINT8_C(0)
#endif

/*!
 * BME280_INTF_RET_TYPE is the read/write interface return type which can be overwritten by the build system.
 */
#ifndef BME280_INTF_RET_TYPE
#define BME280_INTF_RET_TYPE                      int8_t
#endif

/*!
 * The last error code from read/write interface is stored in the device structure as intf_rslt.
 */
#ifndef BME280_INTF_RET_SUCCESS
#define BME280_INTF_RET_SUCCESS                   INT8_C(0)
#endif

/*! @name API success code */
#define BME280_OK                                 INT8_C(0)

/*! @name API error codes */
#define BME280_E_NULL_PTR                         INT8_C(-1)
#define BME280_E_COMM_FAIL                        INT8_C(-2)
#define BME280_E_INVALID_LEN                      INT8_C(-3)
#define BME280_E_DEV_NOT_FOUND                    INT8_C(-4)
#define BME280_E_SLEEP_MODE_FAIL                  INT8_C(-5)
#define BME280_E_NVM_COPY_FAILED                  INT8_C(-6)

/*! @name API warning codes */
#define BME280_W_INVALID_OSR_MACRO                INT8_C(1)

/*! @name BME280 chip identifier */
#define BME280_CHIP_ID                            UINT8_C(0x60)

/*! @name I2C addresses */
#define BME280_I2C_ADDR_PRIM                      UINT8_C(0x76)
#define BME280_I2C_ADDR_SEC                       UINT8_C(0x77)

/*! @name Register Address */
#define BME280_REG_CHIP_ID                        UINT8_C(0xD0)
#define BME280_REG_RESET                          UINT8_C(0xE0)
#define BME280_REG_TEMP_PRESS_CALIB_DATA          UINT8_C(0x88)
#define BME280_REG_HUMIDITY_CALIB_DATA            UINT8_C(0xE1)
#define BME280_REG_CTRL_HUM                       UINT8_C(0xF2)
#define BME280_REG_STATUS                         UINT8_C(0xF3)
#define BME280_REG_PWR_CTRL                       UINT8_C(0xF4)
#define BME280_REG_CTRL_MEAS                      UINT8_C(0xF4)
#define BME280_REG_CONFIG                         UINT8_C(0xF5)
#define BME280_REG_DATA                           UINT8_C(0xF7)

/*! @name Macros related to size */
#define BME280_LEN_TEMP_PRESS_CALIB_DATA          UINT8_C(26)
#define BME280_LEN_HUMIDITY_CALIB_DATA            UINT8_C(7)
#define BME280_LEN_P_T_H_DATA                     UINT8_C(8)

/*! @name Sensor power modes */
#define BME280_POWERMODE_SLEEP                    UINT8_C(0x00)
#define BME280_POWERMODE_FORCED                   UINT8_C(0x01)
#define BME280_POWERMODE_NORMAL                   UINT8_C(0x03)
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

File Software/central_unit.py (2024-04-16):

import struct
import time
import socket
import network
import urequests as requests
import umail
import gc
from machine import Pin, I2C, PWM
from ssd1306 import SSD1306_I2C
import utime
import json
import framebuf

# --- Display Configuration ---
i2c = I2C(1, sda=Pin(2), scl=Pin(3))
display = SSD1306_I2C(128, 64, i2c)

URL = "https://ap-south-1.aws.data.mongodb-api.com/app/data-ibwwd/endpoint/data/v1/action/"
API_KEY = "" # Relace with complete API key

# Replace with the actual IP address of the server
SERVER_ADDR = ""

# Constants (matching the server)
BUF_SIZE = 60 + 1024  # Adjust this if your server uses a different value
SERVER_PORT =   # Mention the port used for communication 
format_string = "IfffffffffffffI" + "h"*512  # Format of the struct data you are trying to receive

# Define your thresholds (Both upper and lower caps)
TEMPERATURE_THRESHOLD_U = 45 
HUMIDITY_THRESHOLD_U = 40 
VARMS_THRESHOLD_U = 250 
VBRMS_THRESHOLD_U = 250
IARMS_THRESHOLD_U = 10 
IBRMS_THRESHOLD_U = 10 
POWERA_THRESHOLD_U = 2500
POWERB_THRESHOLD_U = 2500
TEMPERATURE_THRESHOLD_L = -1
HUMIDITY_THRESHOLD_L = -1
VARMS_THRESHOLD_L = -1
VBRMS_THRESHOLD_L = -1 
IARMS_THRESHOLD_L = -1 
IBRMS_THRESHOLD_L = -1
POWERA_THRESHOLD_L = -1
POWERB_THRESHOLD_L = -1

# --- Buzzer Configuration ---
BUZZER_PIN = 15
BUZZER_FREQUENCY = 500
BUZZER_DURATION = 1  # Seconds
BUZZER_DUTY_CYCLE = 100  # Percent

NTFY_TOPIC = "" # Name of the ntfy topic where you want send notifications
NTFY_URL = "https://ntfy.sh/" + NTFY_TOPIC
        
def insertOne_sensor(time, VArms, VBrms, IArms, IBrms, PowerA, PowerB, PfA, PfB, freqA, freqB, temp, pressure, humidity):
    try:
        headers = { "api-key": API_KEY }
        documentToAdd = {"Time": time,
                         "VArms": VArms,
                         "VBrms": VBrms,
                         "IArms": IArms,
                         "IBrms": IBrms,
                         "PowerA": PowerA,
                         "PowerB": PowerB,
                         "PfA": PfA,
                         "PfB": PfB,
                         "freqA": freqA,
                         "freqB": freqB,
                         "Temperature (C)": temp,
                         "Pressure": pressure,
                         "Humidity": humidity,
                         }
        
        insertPayload = {
            "dataSource": "Cluster0",
            "database": "SensorData",
            "collection": "Sensor",
            "document": documentToAdd,
        }
        response = requests.post(URL + "insertOne", headers=headers, json=insertPayload)
        print(response)
        print("Response: (" + str(response.status_code) + "), msg = " + str(response.text))
        if response.status_code >= 200 and response.status_code < 300:
            print("Success Response")
        else:
            print(response.status_code)
            print("Error")
        response.close()
    except Exception as e:
        print(e)

def insertOne_waveform(waveform, time):
    try:
        headers = { "api-key": API_KEY }
        documentToAdd = {"Waveform Array": waveform,
                         "Time": time}
        
        insertPayload = {
            "dataSource": "Cluster0",
            "database": "SensorData",
            "collection": "Waveform",
            "document": documentToAdd,
        }
        response = requests.post(URL + "insertOne", headers=headers, json=insertPayload)
        print(response)
        print("Response: (" + str(response.status_code) + "), msg = " + str(response.text))
        if response.status_code >= 200 and response.status_code < 300:
            print("Success Response")
        else:
            print(response.status_code)
            print("Error")
        response.close()
    except Exception as e:
        print(e)

def insertMany_sensor(document_list):
    try:
        headers = { "api-key": API_KEY }
        insertPayload = {
            "dataSource": "Cluster0",
            "database": "SensorData",
            "collection": "Sensor",
            "documents": document_list,
        }
        response = requests.post(URL + "insertMany", headers=headers, json=insertPayload)
        print("Response: (" + str(response.status_code) + "), msg = " + str(response.text))
        if response.status_code >= 200 and response.status_code < 300:
            print("Success Response")
        else:
            print(response.status_code)
            print("Error")
        response.close()
    except Exception as e:
        print(e)

def insertMany_waveform(document_list):
    try:
        headers = { "api-key": API_KEY }
        insertPayload = {
            "dataSource": "Cluster0",
            "database": "SensorData",
            "collection": "Waveform",
            "documents": document_list,
        }
        response = requests.post(URL + "insertMany", headers=headers, json=insertPayload)
        print("Response: (" + str(response.status_code) + "), msg = " + str(response.text))
        if response.status_code >= 200 and response.status_code < 300:
            print("Success Response")
        else:
            print(response.status_code)
            print("Error")
        response.close()
    except Exception as e:
        print(e)
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

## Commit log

2024-02-13 Add init schematic
    [energy_meter.kicad_pcb, energy_meter.kicad_sch]
2024-02-20 Schematic progress
    [energy_meter.kicad_sch, energy_meter2.kicad_sch]
2024-03-03 Progress in schematic
    [energy_meter.kicad_pcb, energy_meter.kicad_sch]
2024-03-03 Finish up schematic
    [energy_meter.kicad_pcb, energy_meter.kicad_sch]
2024-03-03 Add lipo battery terminal
    [energy_meter.kicad_pcb, energy_meter.kicad_sch]
2024-03-03 Minor changes
    [energy_meter.kicad_pcb, energy_meter.kicad_sch]
2024-03-04 finish schematic started on layout
    [energy_meter.kicad_pcb, energy_meter.kicad_sch]
2024-03-05 Add pdf of schematic
    [central.kicad_sch, central_unit.kicad_sch, energy_meter.kicad_sch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]
2024-03-10 Example code
    [central.kicad_sch, energy_meter.kicad_sch]
2024-03-12 Add central unit
    [central_unit.kicad_pcb, central_unit.kicad_sch]
2024-03-12 Initial ade9000 driver
2024-03-16 Remove banana cliffs
    [energy_meter.kicad_pcb, energy_meter.kicad_sch]
2024-03-16 Basic layout
    [energy_meter.kicad_pcb, energy_meter.kicad_sch]
2024-03-16 finished layout
    [central.kicad_sch, energy_meter.kicad_pcb, energy_meter.kicad_sch]
2024-03-16 Restore libraries
    [energy_meter.kicad_sch]
2024-03-16 more libraries
    [energy_meter.kicad_pcb, energy_meter.kicad_sch]
2024-03-17 pcb routing1
    [energy_meter.kicad_pcb, energy_meter.kicad_sch]
2024-03-17 Complete routing of sensing unit
    [central_unit.kicad_pcb, central_unit.kicad_sch, energy_meter.kicad_pcb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]
2024-03-19 Silkscreen done
    [energy_meter.kicad_pcb]
2024-03-20 Add bitmaps
    [energy_meter.kicad_pcb]
2024-03-27 Major progress
    [energy_meter.kicad_pcb, energy_meter.kicad_sch, energy_meter_laser_cutting.dxf]
2024-03-28 Conversion factors added to Arduino code
    [energy_meter.kicad_pcb]
2024-04-03 Get upto date
    [energy_meter.csv]
2024-04-12 Prototype ready!
    [energy_meter.csv, energy_meter.kicad_pcb, energy_meter.kicad_sch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]
2024-04-15 Prepare for final submission
    [box final final.dxf, readings.csv]
2024-04-15 Update and rename BME280.csv to sample_bme280.csv
    [sample_bme280.csv]
2024-04-15 Update and rename readings.csv to sample_data.csv
    [sample_data.csv]
2024-04-16 Update and rename readings.csv to sample_sensor.csv
    [sample_sensor.csv]
